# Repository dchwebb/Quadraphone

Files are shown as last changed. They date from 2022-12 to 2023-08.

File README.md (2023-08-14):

# Quadraphone
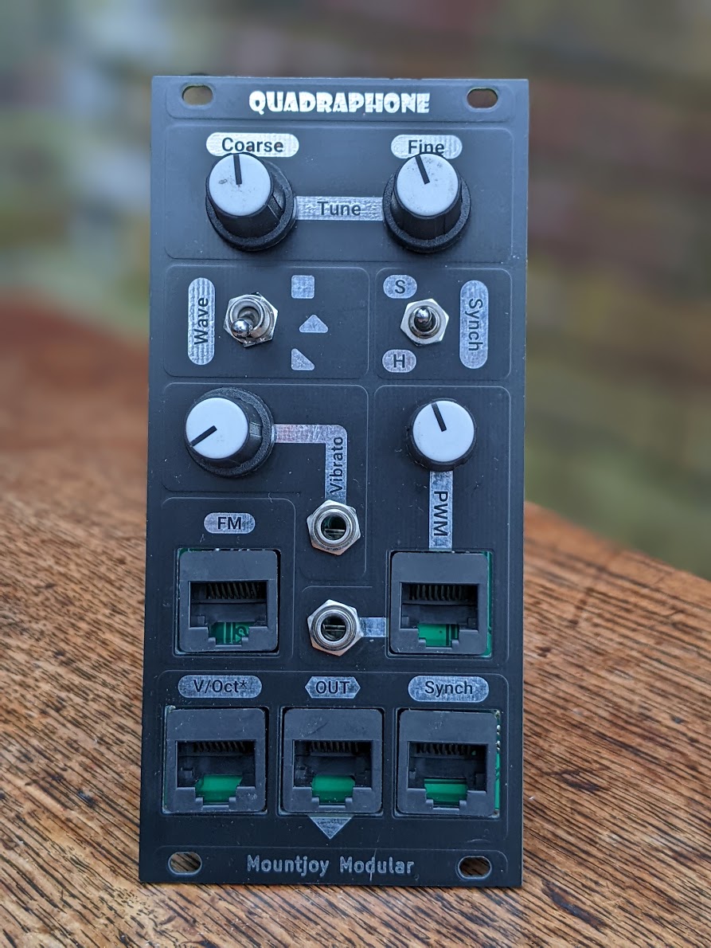
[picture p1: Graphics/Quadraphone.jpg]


Quadraphone
--------

Quadraphone is a four voice polyphonic analog Voltage Controlled Oscillator for use within a Eurorack Modular Synthesiser. Polyphonic signal interconnections are made via RJ-45 cables (ie Ethernet cables).

Quadraphone features a switchable output of square, triangle and saw waves. Pulse Width Modulation (PWM) is available for the square wave, polyphonically via an RJ-45 input or across all voices via a 3.5mm jack. A potentiometer sets the default pulse width across all voices.

Polyphonic synch is available and a switch allows selection of hard, soft or off settings. Exponentional FM is available on an Rj-45 connection and vibrato (linear FM) is available via a 3.5mm jack with potentiometer attenuation.

A volt per octave input is available on an RJ-45 connector. Pins 1-4 carry the control voltage input and pins 5-8 carry the output signal (also available on an RJ-45) for easy module interconnection. Coarse and Fine tune potentiometers affect all voices.

Technical
---------

Each Quadraphone voice is based around the [Sound Semiconductor SSI2131 Fatkeys VCO](https://www.soundsemiconductor.com/).

Each VCO outputs three voices (pulse, triangle and saw) which are switched via Nexperia 74LV4066PW analog switches. 74LV4066PW ICs are also used to switch incoming synch signals between the hard, soft and off selections.

Each voice has trimmers to control base frequency, exponential scaling and high frequency tracking.

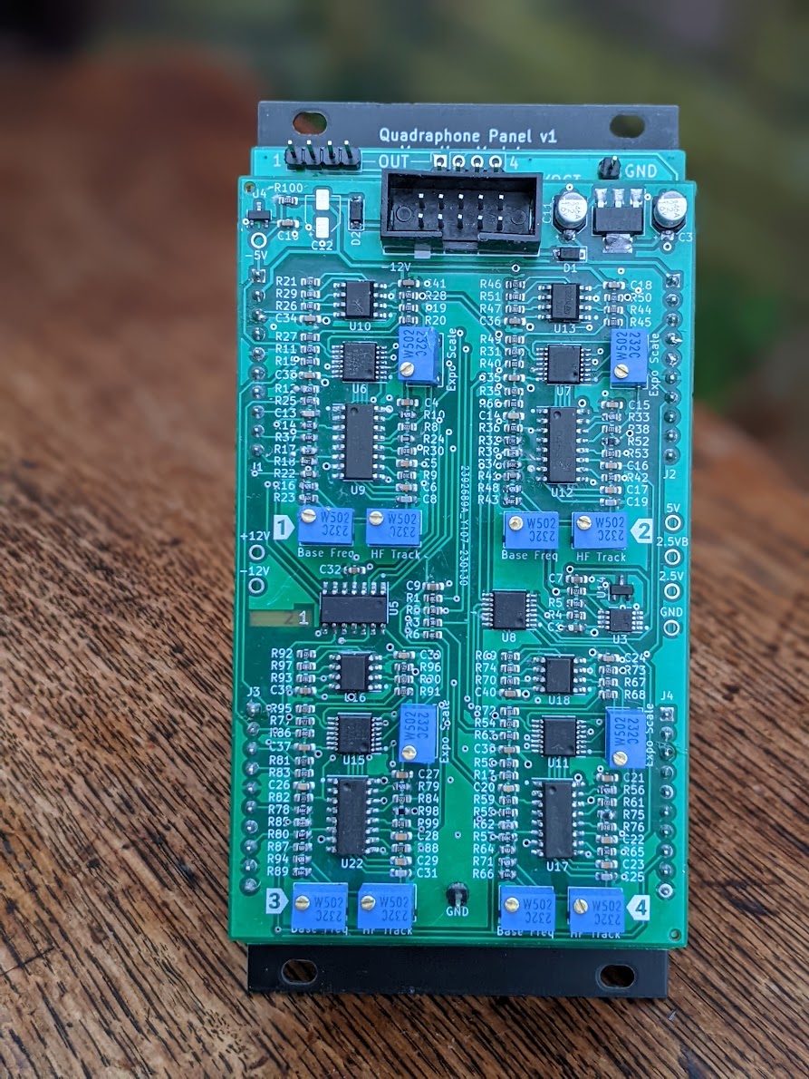
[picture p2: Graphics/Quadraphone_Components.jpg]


Construction is a sandwich of three PCBs with a component board, a controls board and a panel. PCBs designed in Kicad v6.

[Components schematic](https://raw.githubusercontent.com/dchwebb/Quadraphone/master/Quadraphone_Components.pdf)

[Controls schematic](https://raw.githubusercontent.com/dchwebb/Quadraphone/master/Quadraphone_Controls.pdf)

In addition the the Eurorack +/-12V rails (which have polarity protection and filtering) a 5v rail is supplied using an AMS1117-5.0 LDO. A 2.5v rail is generated with an LM4040DBZ-2.5 and buffered with an MCP6002 opamp and a -5v reference is generated with an LM4040DBZ-5.0.

+12V current draw: 44mA
-12V current draw: 34mA

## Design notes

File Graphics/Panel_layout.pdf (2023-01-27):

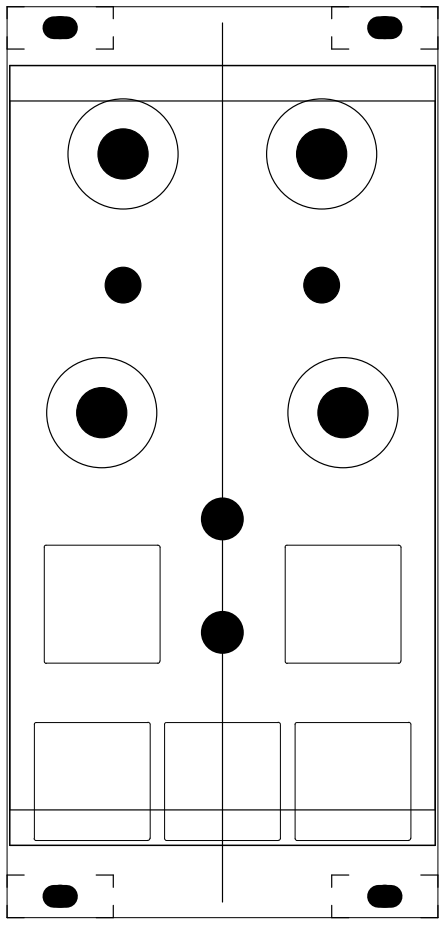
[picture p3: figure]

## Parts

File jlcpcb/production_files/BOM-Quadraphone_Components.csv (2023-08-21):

Comment | Designator | Footprint | LCSC
74LV4066PW | U11,U15,U6,U7,U8 | TSSOP-14_4.4x5mm_P0.65mm | C123051
2k7 | R7 | R_0603_1608Metric | C13167
100nF | C10,C18,C24,C30,C32,C33,C34,C35,C36,C37,C38,C39,C40,C41 | C_0603_1608Metric_Pad1.08x0.95mm_HandSolder | C14663
1uF | C1,C7,C9 | C_0603_1608Metric_Pad1.08x0.95mm_HandSolder | C15849
1nF | C13,C14,C20,C26 | C_0603_1608Metric_Pad1.08x0.95mm_HandSolder | C1588
MMBT3904 | Q1 | SOT-23 | C20526
13k | R1,R14,R2,R3,R36,R4,R59,R6,R82 | R_0603_1608Metric | C22797
1M | R30,R53,R76,R99 | R_0603_1608Metric | C22935
270 | R10,R16,R33,R48,R56,R71,R79,R94 | R_0603_1608Metric | C22966
30k | R19,R20,R26,R27,R44,R45,R47,R49,R67,R68,R70,R72,R90,R91,R93,R95 | R_0603_1608Metric | C22984
49.9k | R18,R22,R32,R34,R37,R41,R55,R57,R64,R78,R80,R87 | R_0603_1608Metric | C23184
510k | R24,R52,R75,R98 | R_0603_1608Metric | C23192
68k | R23,R43,R66,R89 | R_0603_1608Metric | C23231
100k | R13,R15,R25,R40,R60,R63,R83,R86 | R_0603_1608Metric | C25803
10k | R42,R65,R88,R9 | R_0603_1608Metric | C25804
120k | R12,R21,R28,R35,R46,R50,R58,R69,R73,R81,R92,R96 | R_0603_1608Metric | C25808
18k | R29,R51,R74,R97 | R_0603_1608Metric | C25810
47k | R102,R11,R31,R54,R77 | R_0603_1608Metric | C25819
680k | R17,R39,R62,R85 | R_0603_1608Metric | C25822
22k | R38,R61,R8,R84 | R_0603_1608Metric | C31850
20k | R101 | R_0603_1608Metric | C4184
2.2k | R100 | R_0603_1608Metric | C4190
10nF | C15,C16,C17,C21,C22,C23,C27,C28,C29,C4,C5,C6 | C_0603_1608Metric_Pad1.08x0.95mm_HandSolder | C57112
AMS1117-5.0 | U1 | SOT-223-3_TabPin2 | C6187
TL072 | U10,U13,U16,U18 | SOIC-8_3.9x4.9mm_P1.27mm | C6961
MCP6002 | U3 | SOIC-8_3.9x4.9mm_P1.27mm | C7377
1N5819 | D1,D2 | D_SOD-123 | C8598

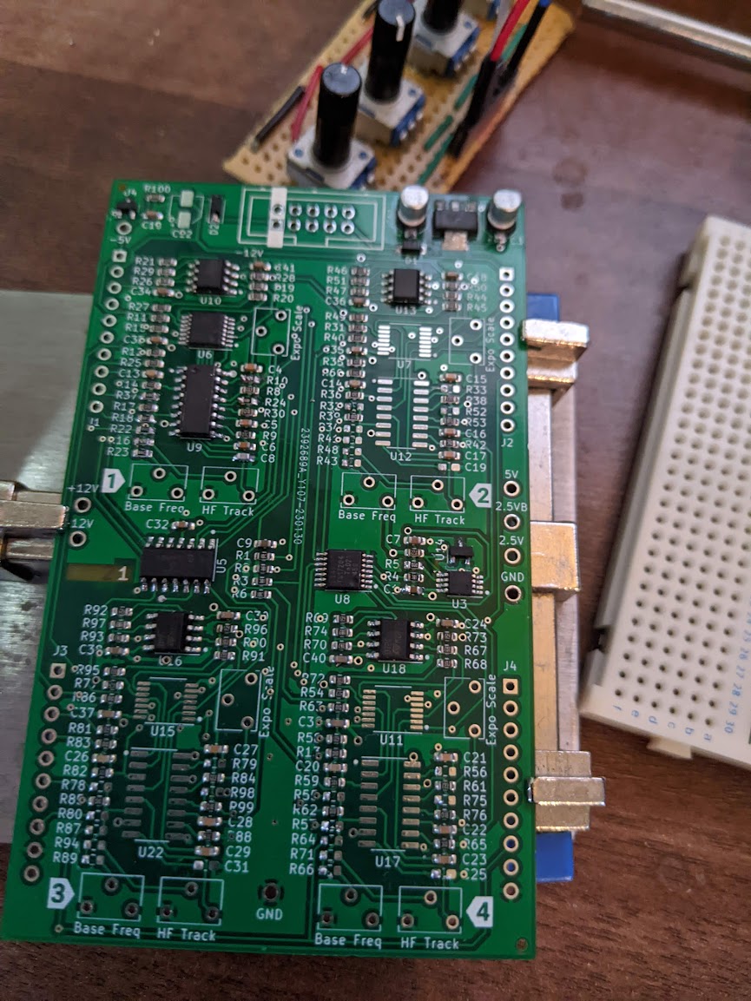
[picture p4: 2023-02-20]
Graphics/Component_Board_WIP.jpg

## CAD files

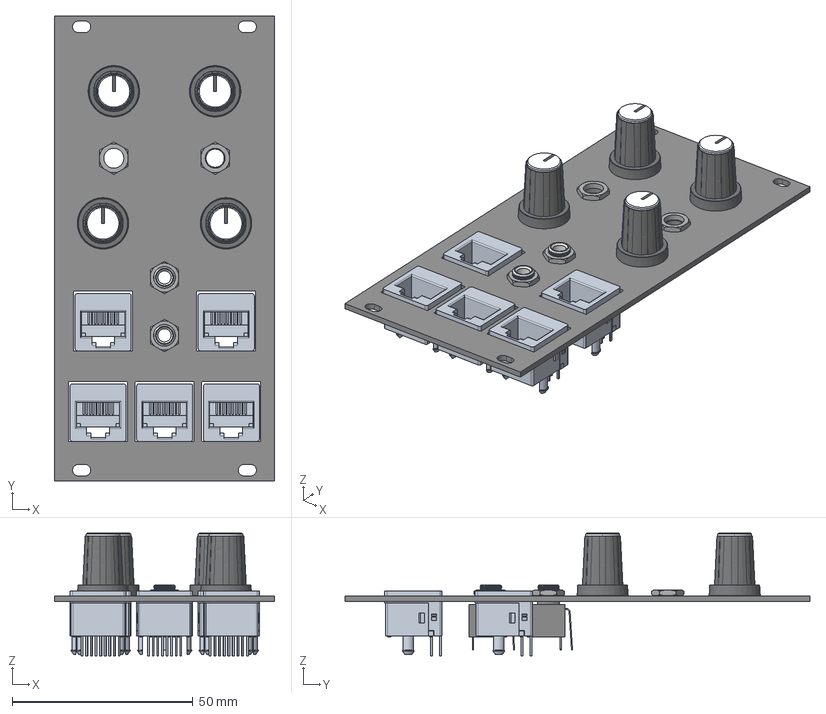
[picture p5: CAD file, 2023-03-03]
Graphics/Quadraphone_Panel.step
60.8 x 128.5 x 34.0 mm
Quadraphone_Panel PCB

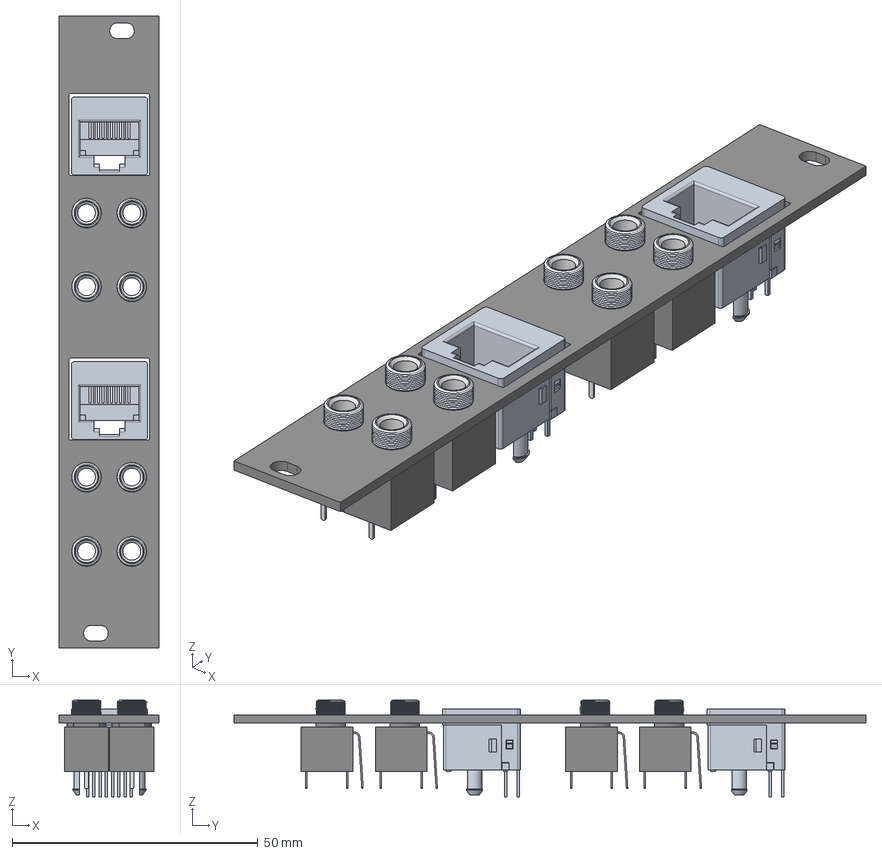
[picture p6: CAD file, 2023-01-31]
V2_Production/Quadraphone_Breakout_Panel.step
20.3 x 128.5 x 19.7 mm
Quadraphone_Breakout_Panel PCB

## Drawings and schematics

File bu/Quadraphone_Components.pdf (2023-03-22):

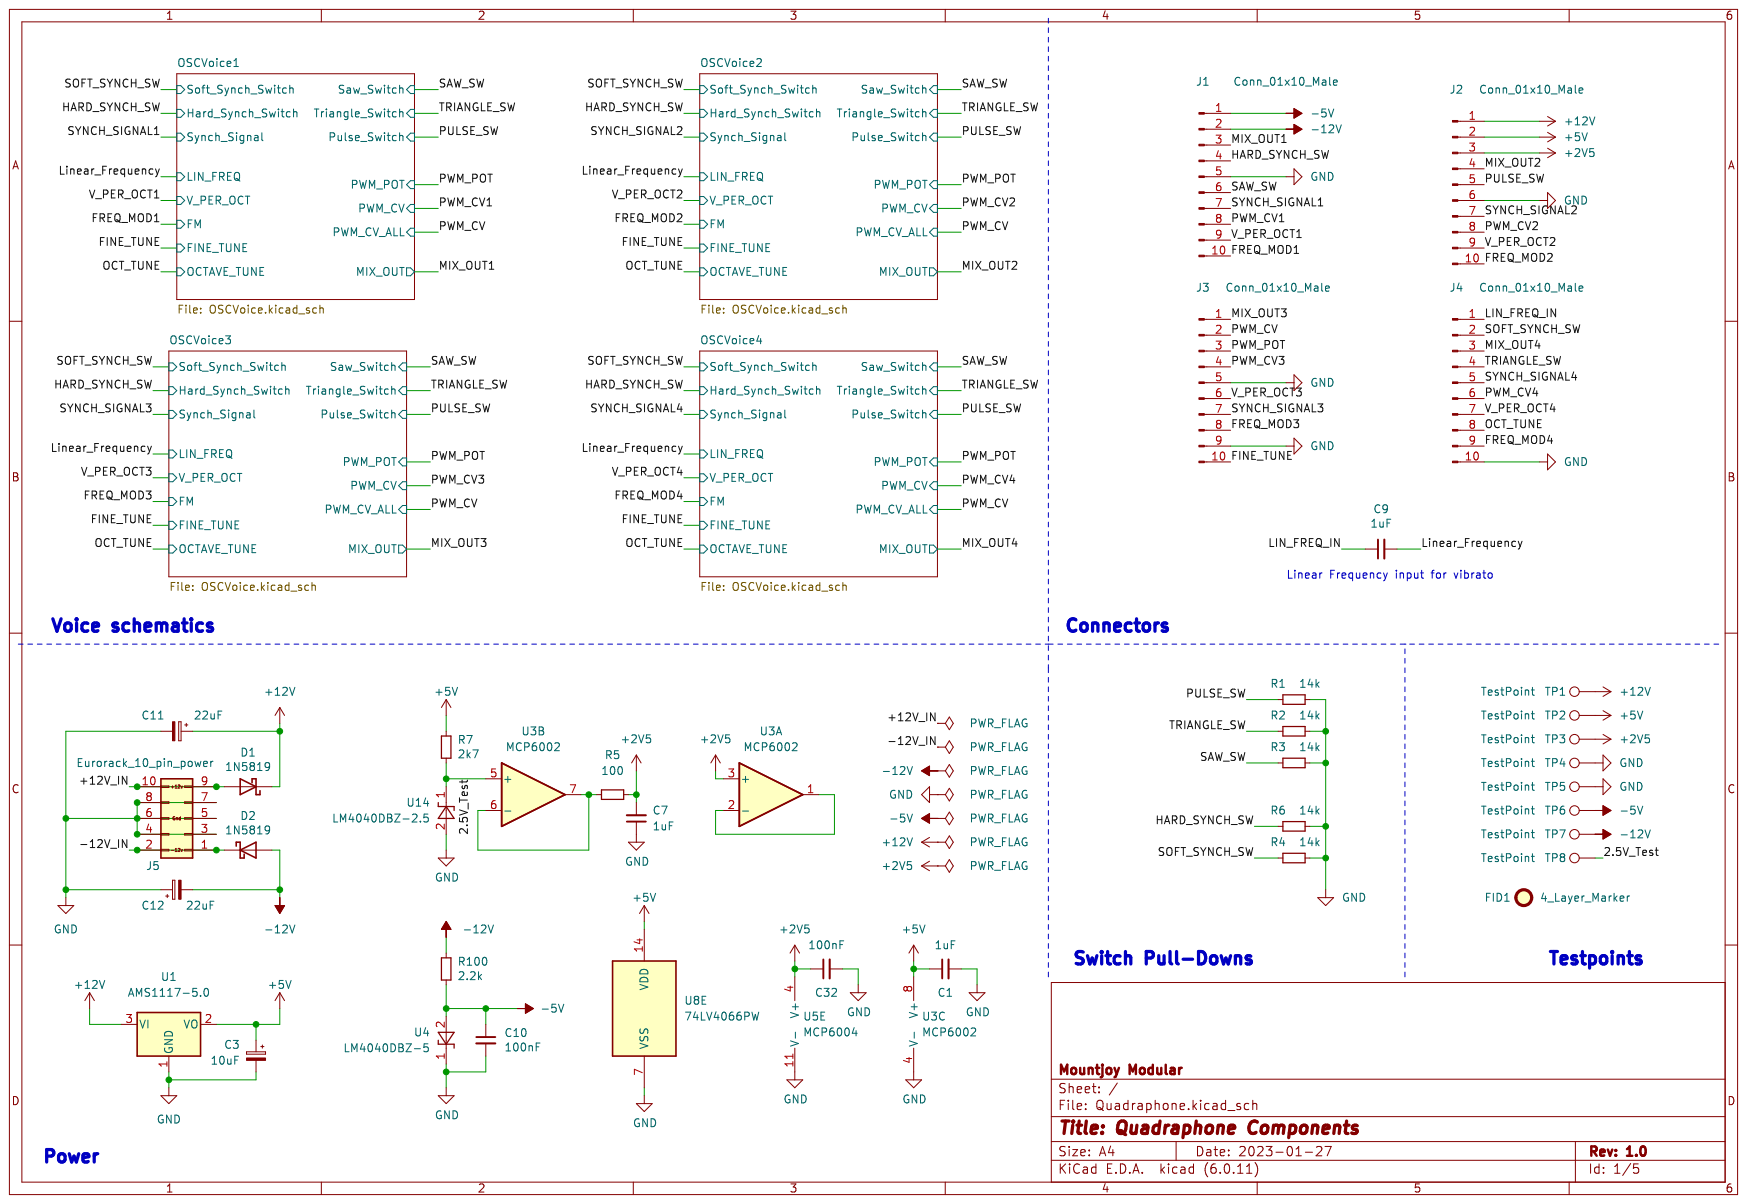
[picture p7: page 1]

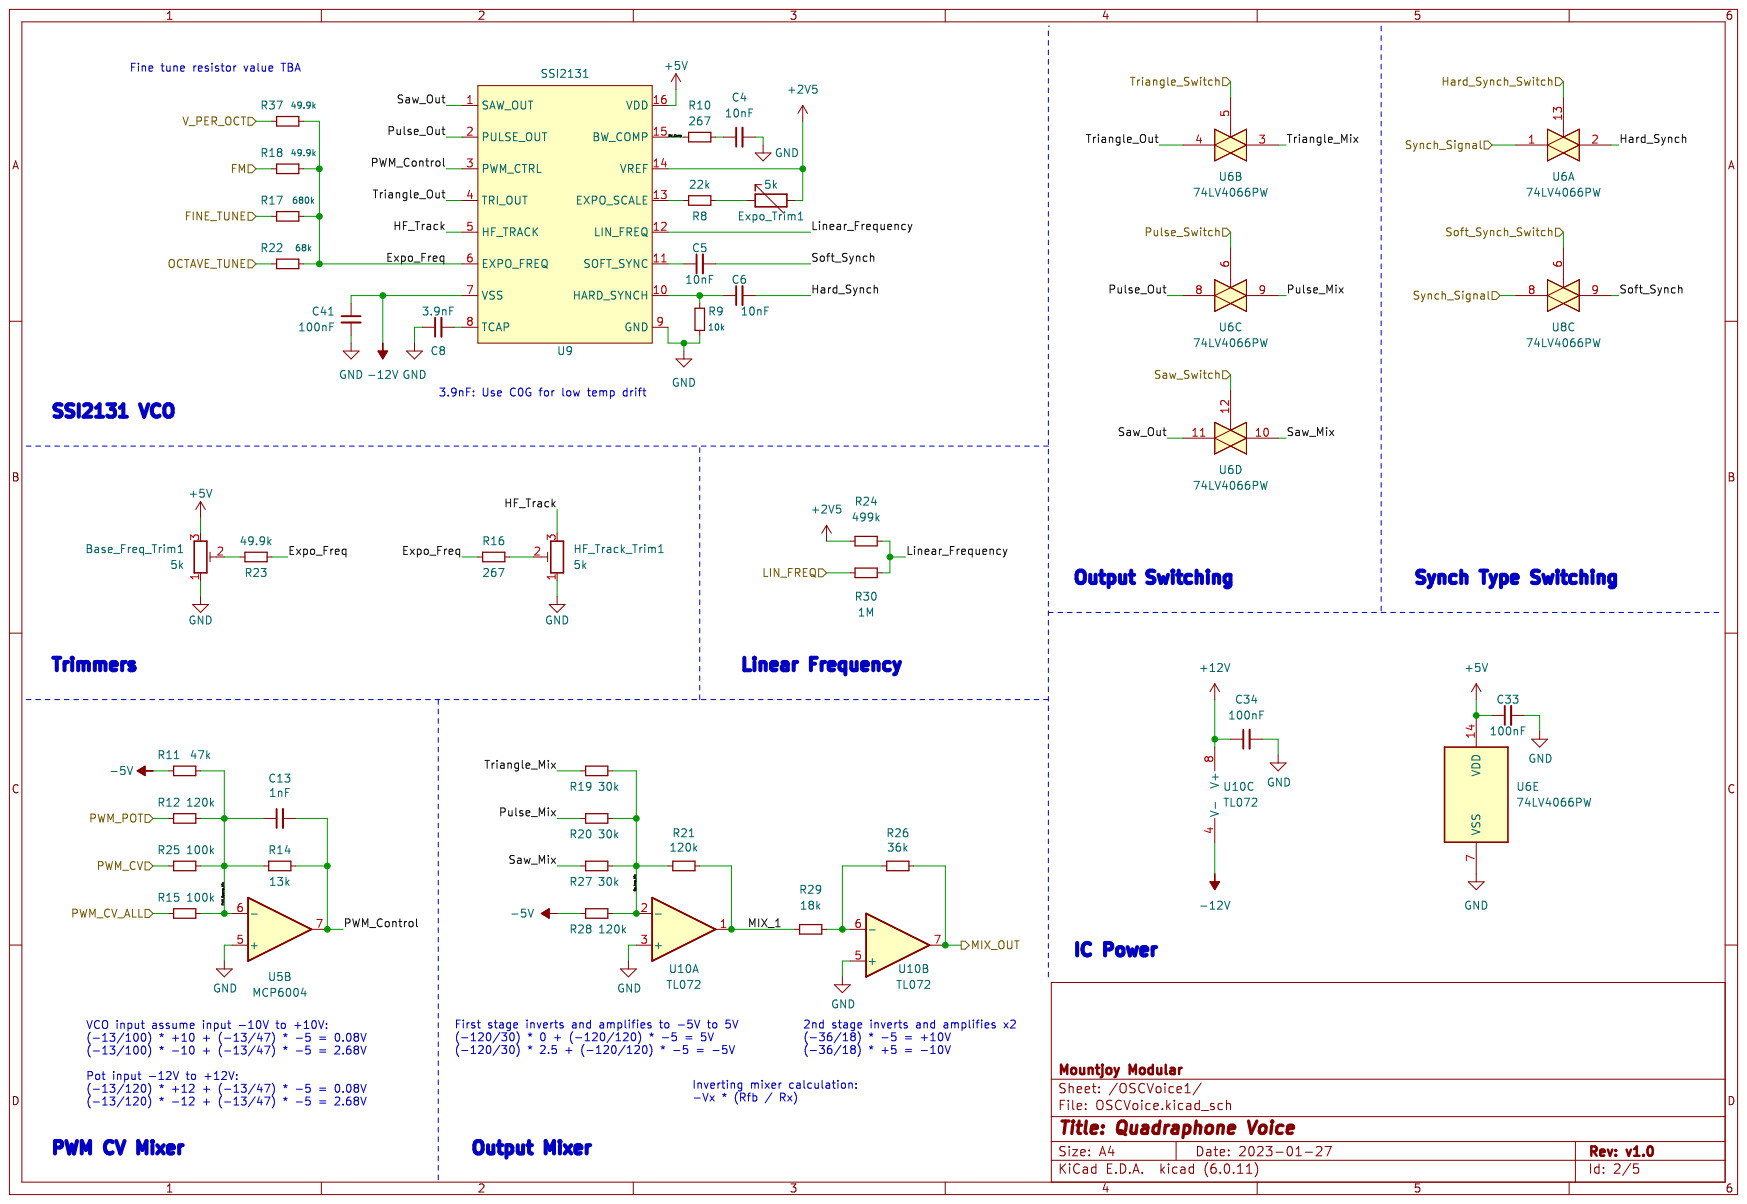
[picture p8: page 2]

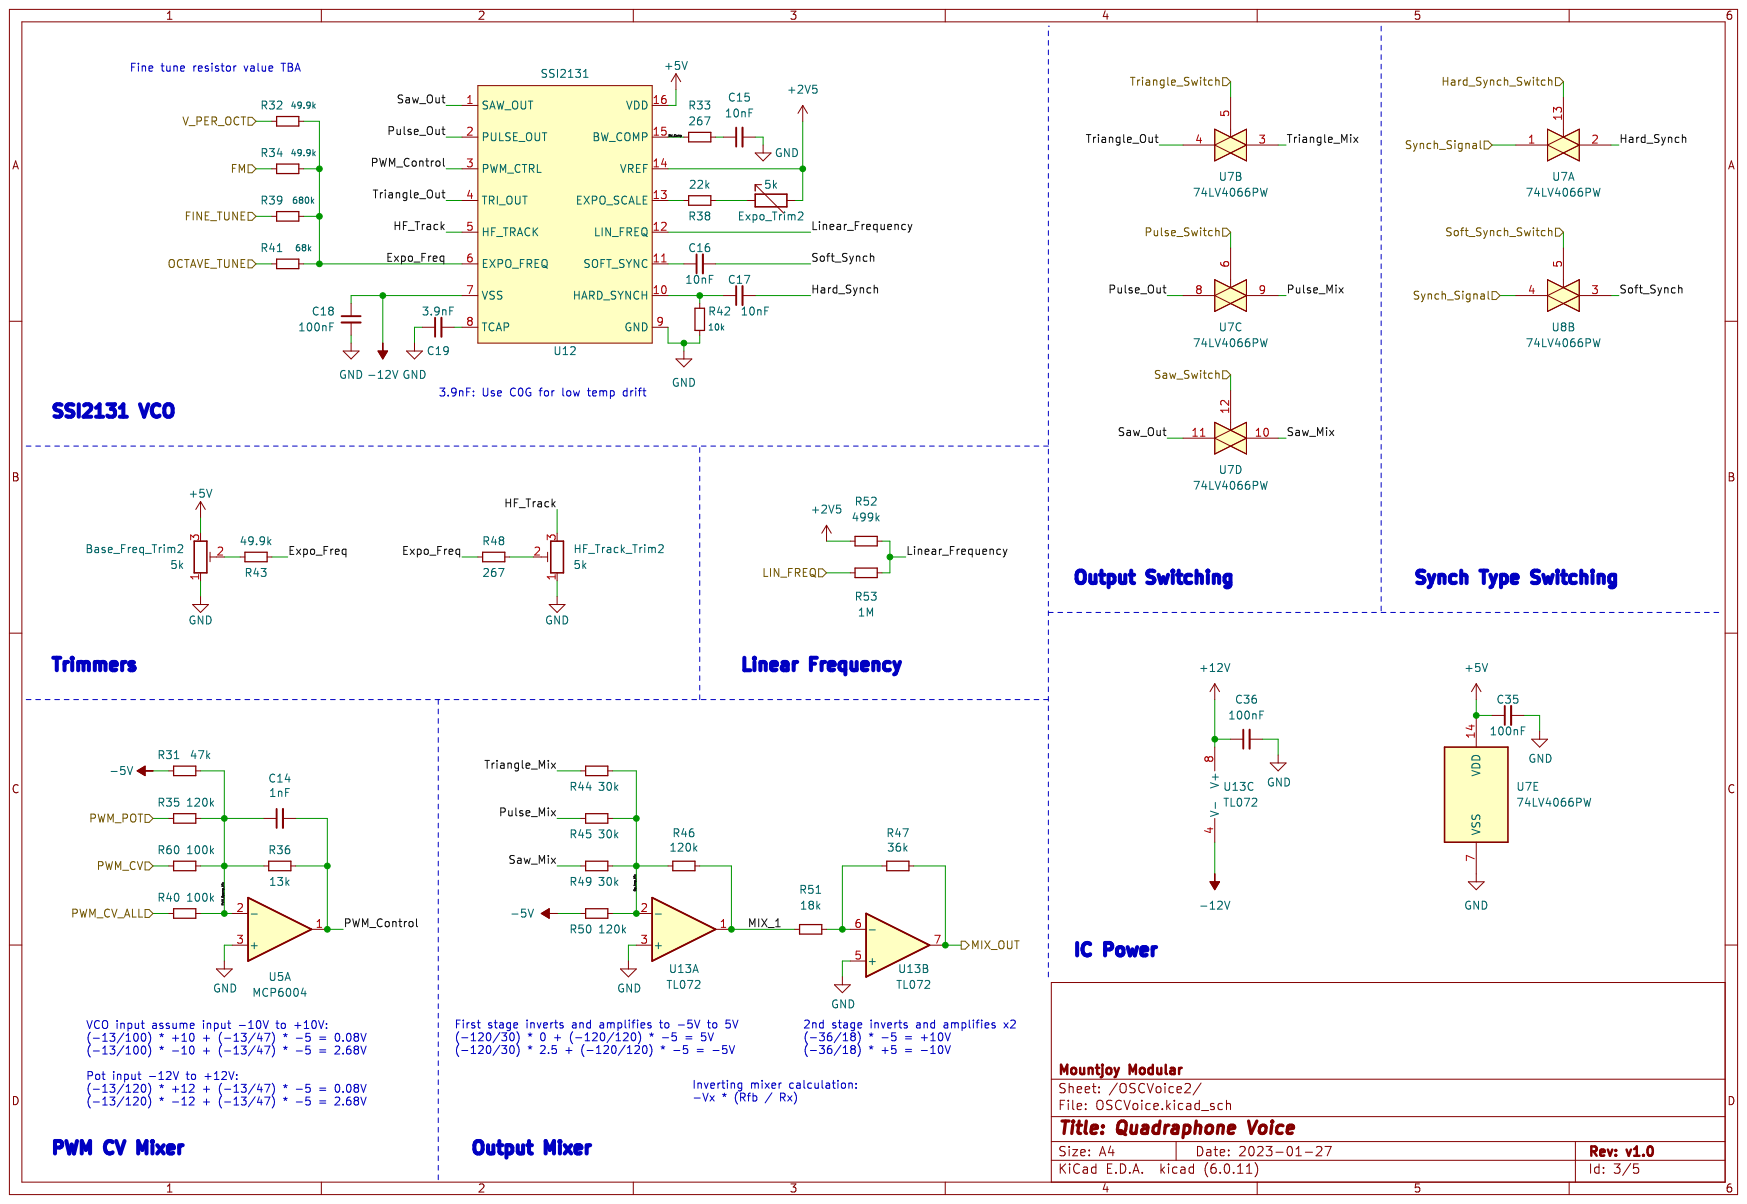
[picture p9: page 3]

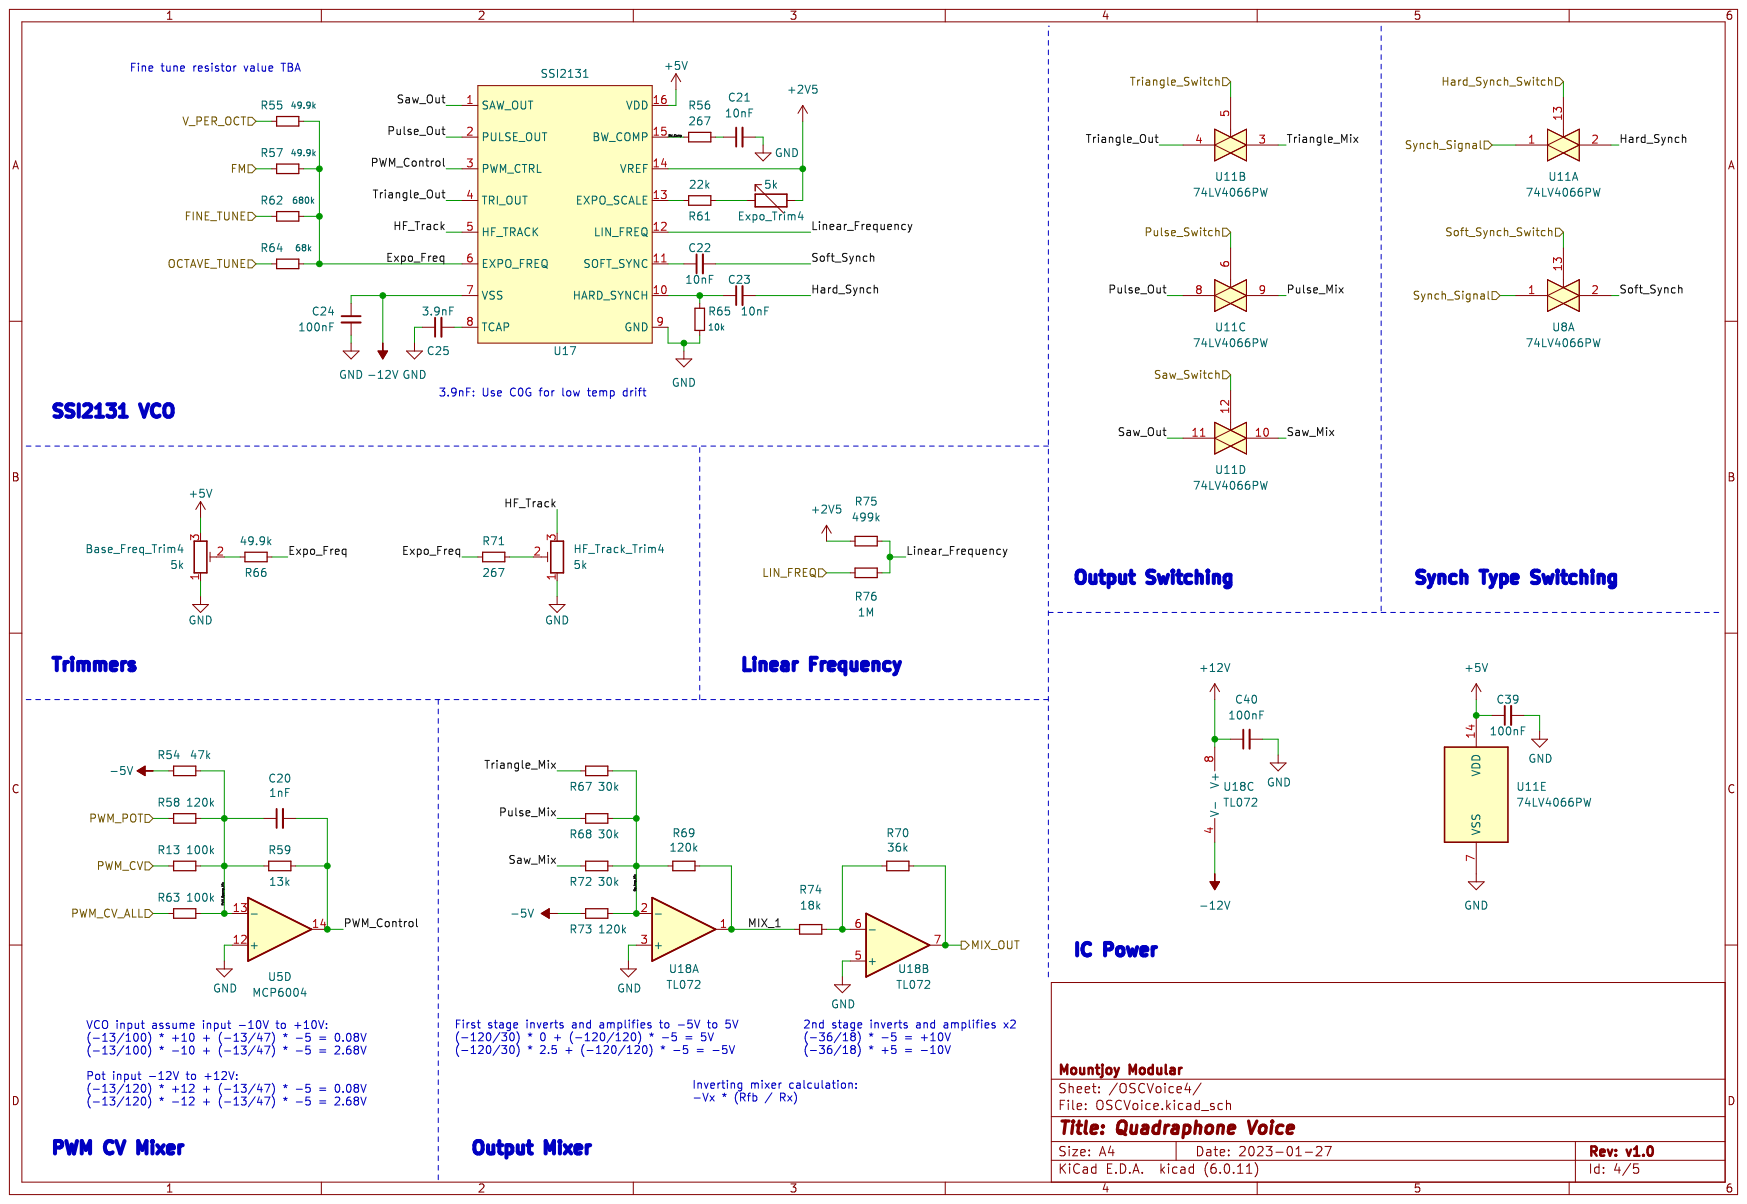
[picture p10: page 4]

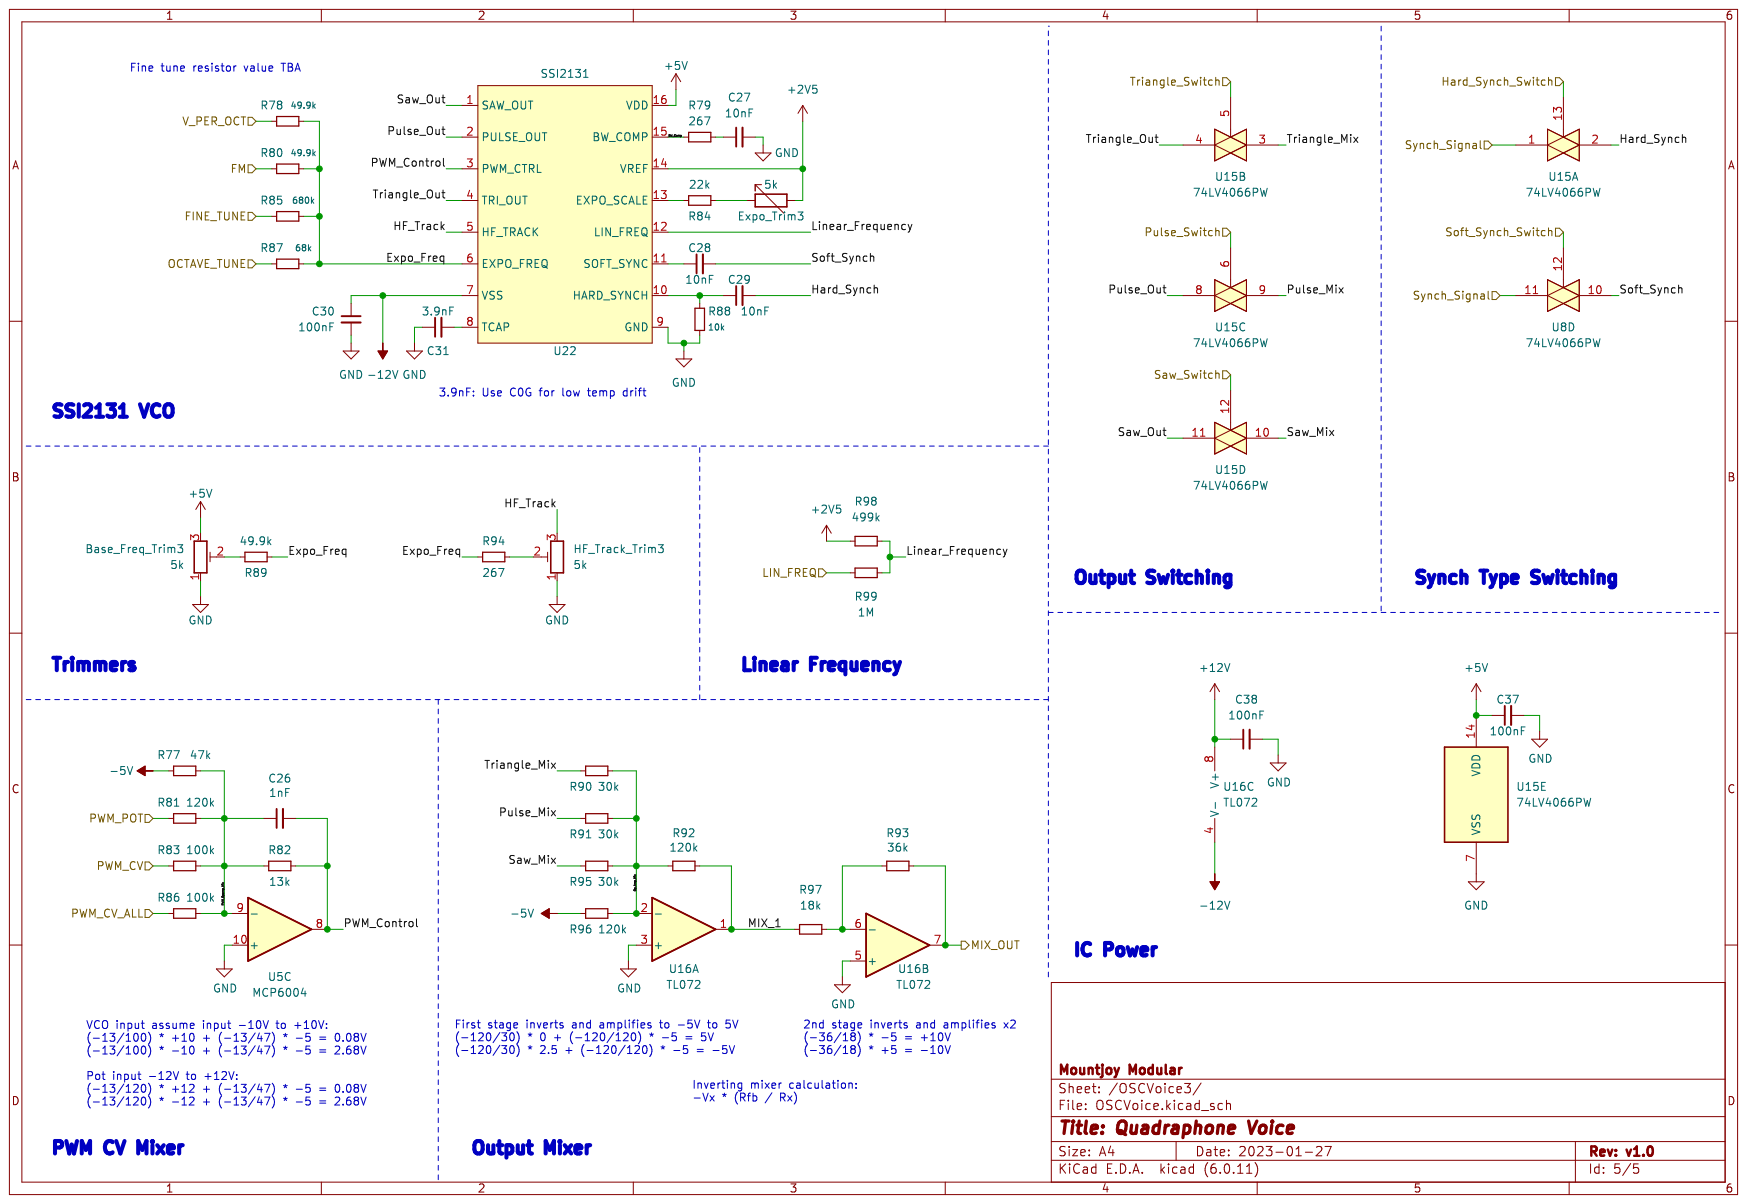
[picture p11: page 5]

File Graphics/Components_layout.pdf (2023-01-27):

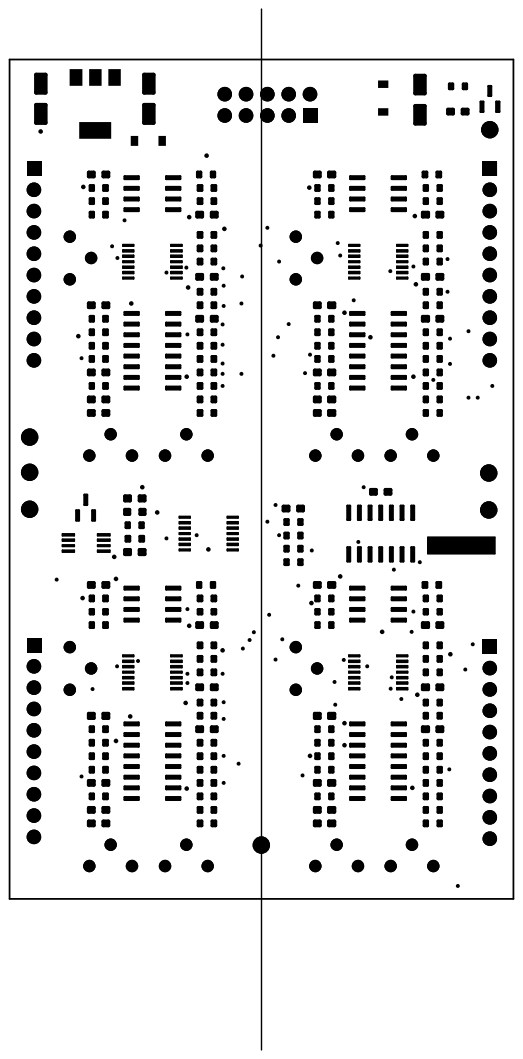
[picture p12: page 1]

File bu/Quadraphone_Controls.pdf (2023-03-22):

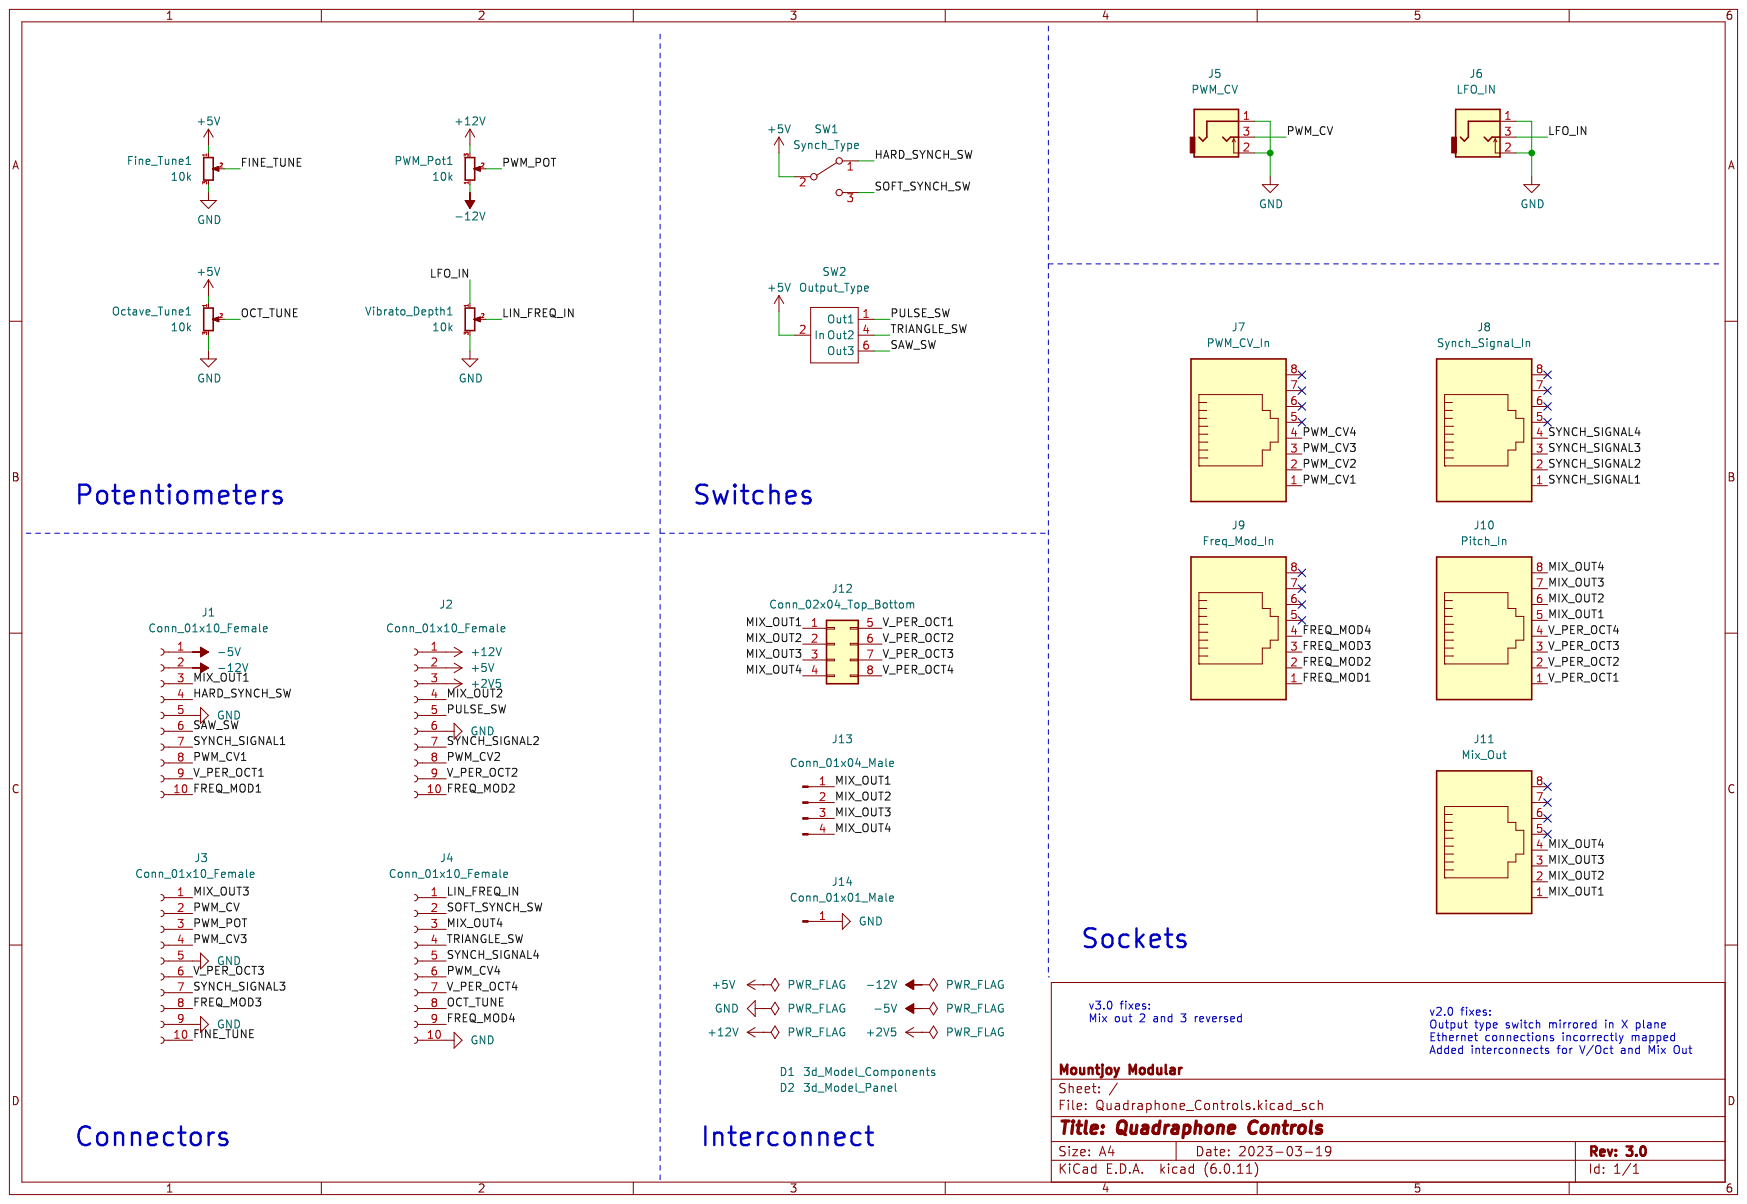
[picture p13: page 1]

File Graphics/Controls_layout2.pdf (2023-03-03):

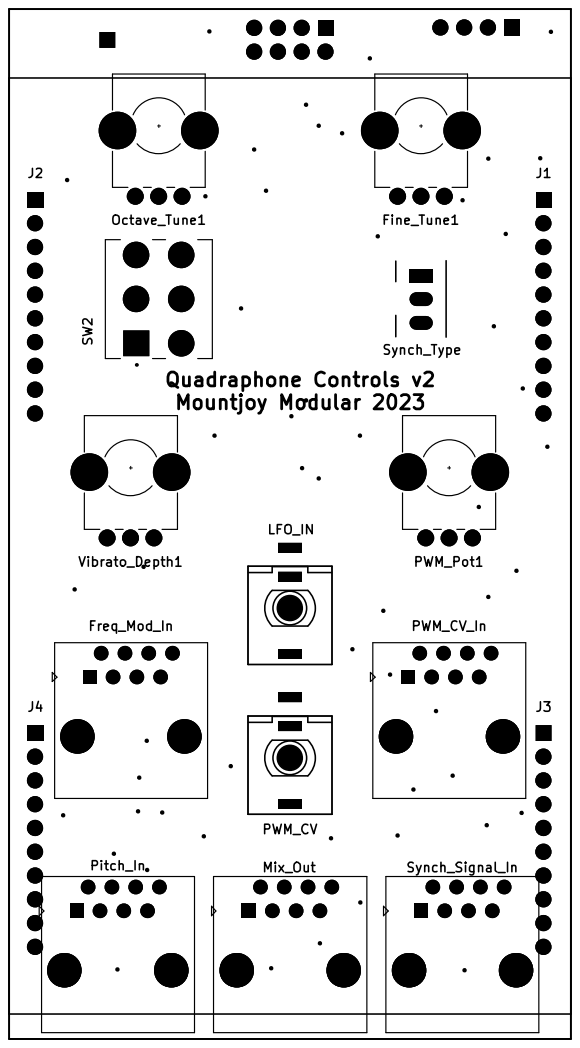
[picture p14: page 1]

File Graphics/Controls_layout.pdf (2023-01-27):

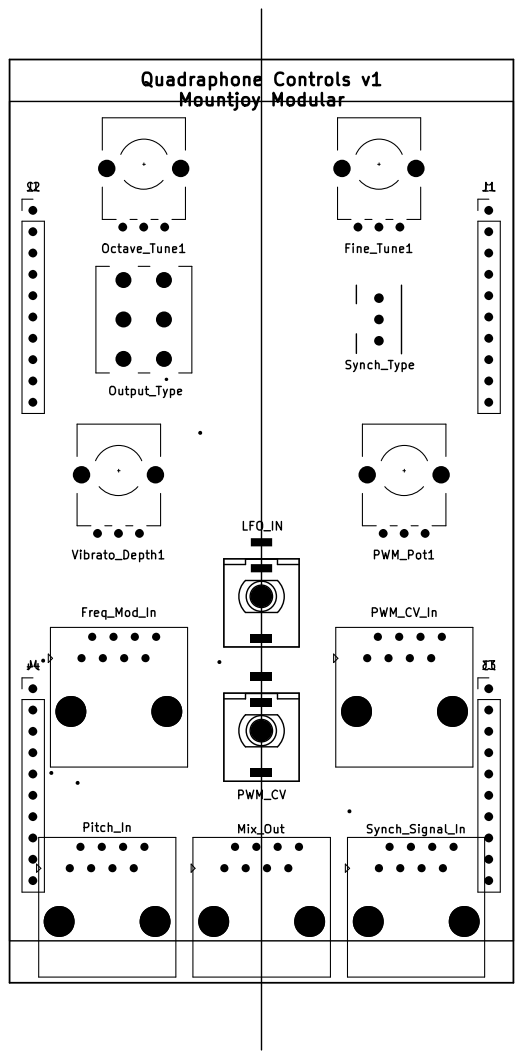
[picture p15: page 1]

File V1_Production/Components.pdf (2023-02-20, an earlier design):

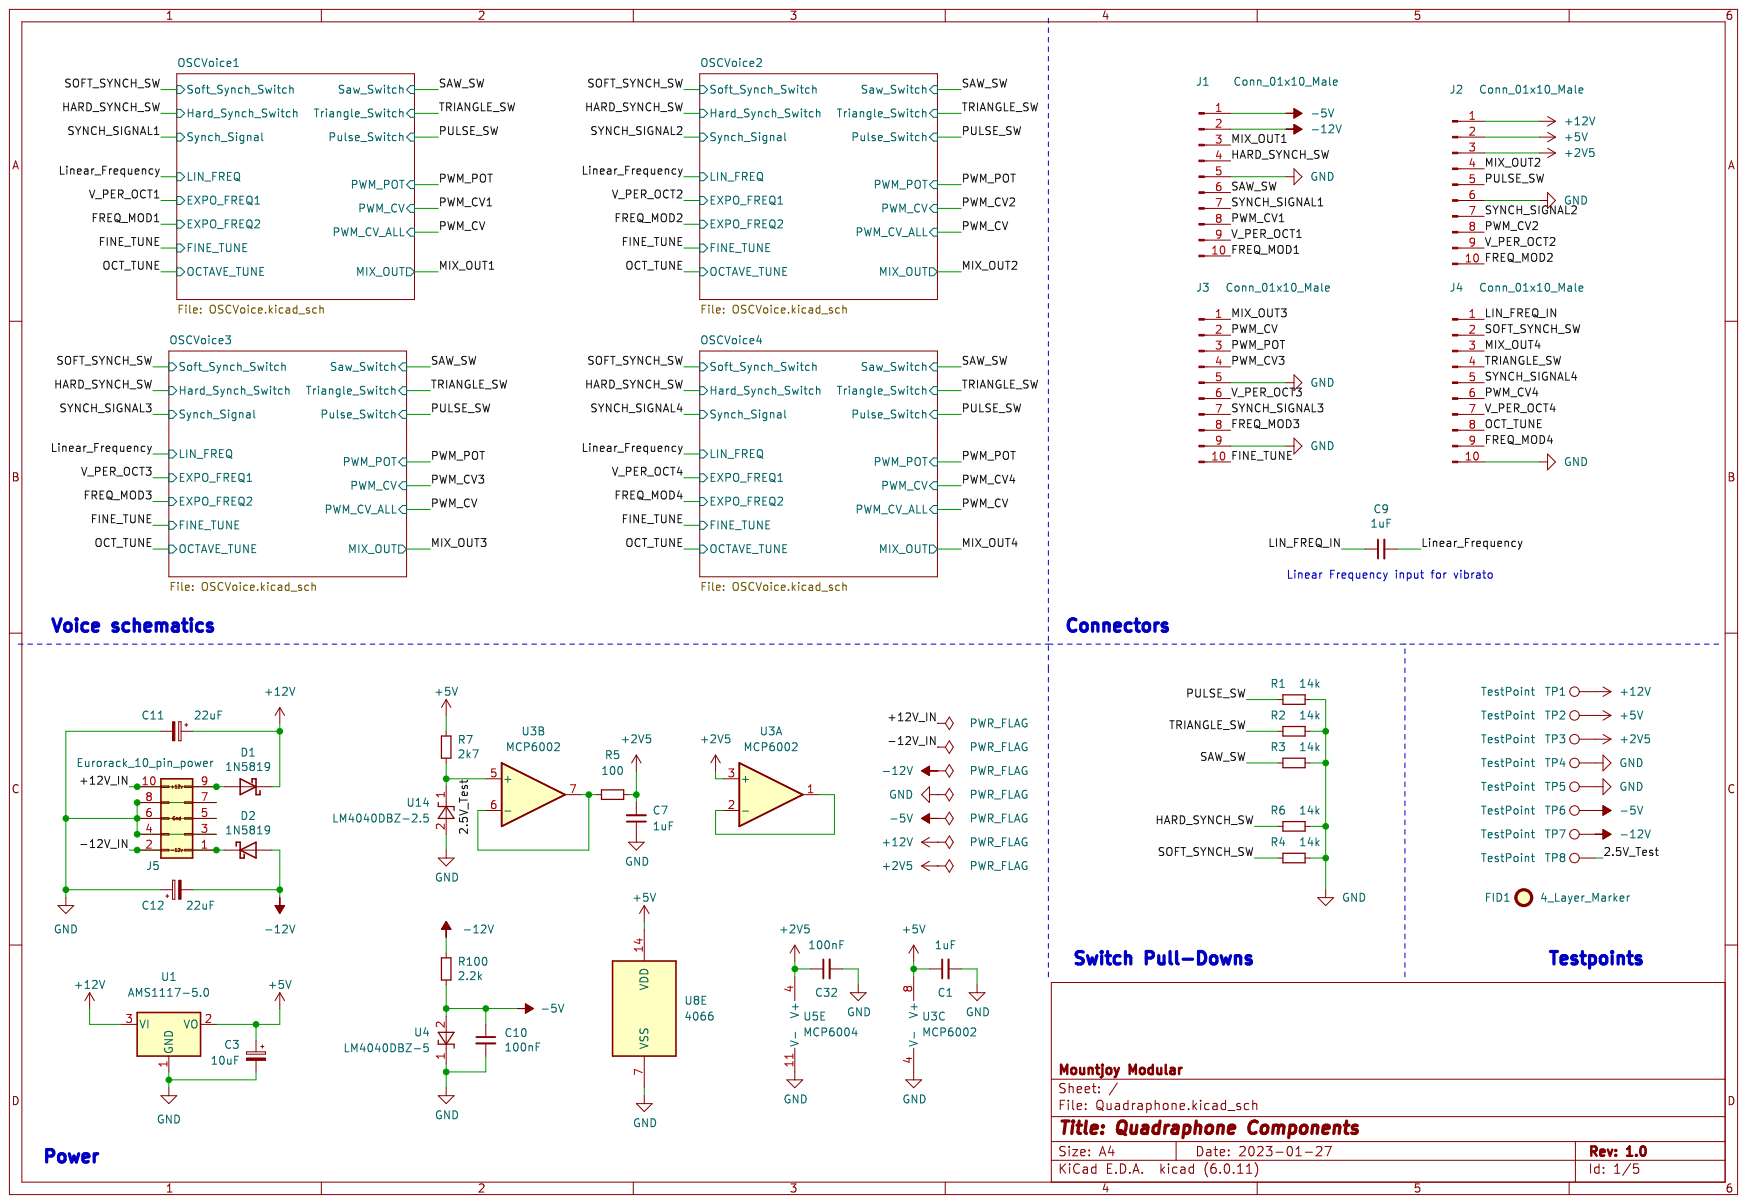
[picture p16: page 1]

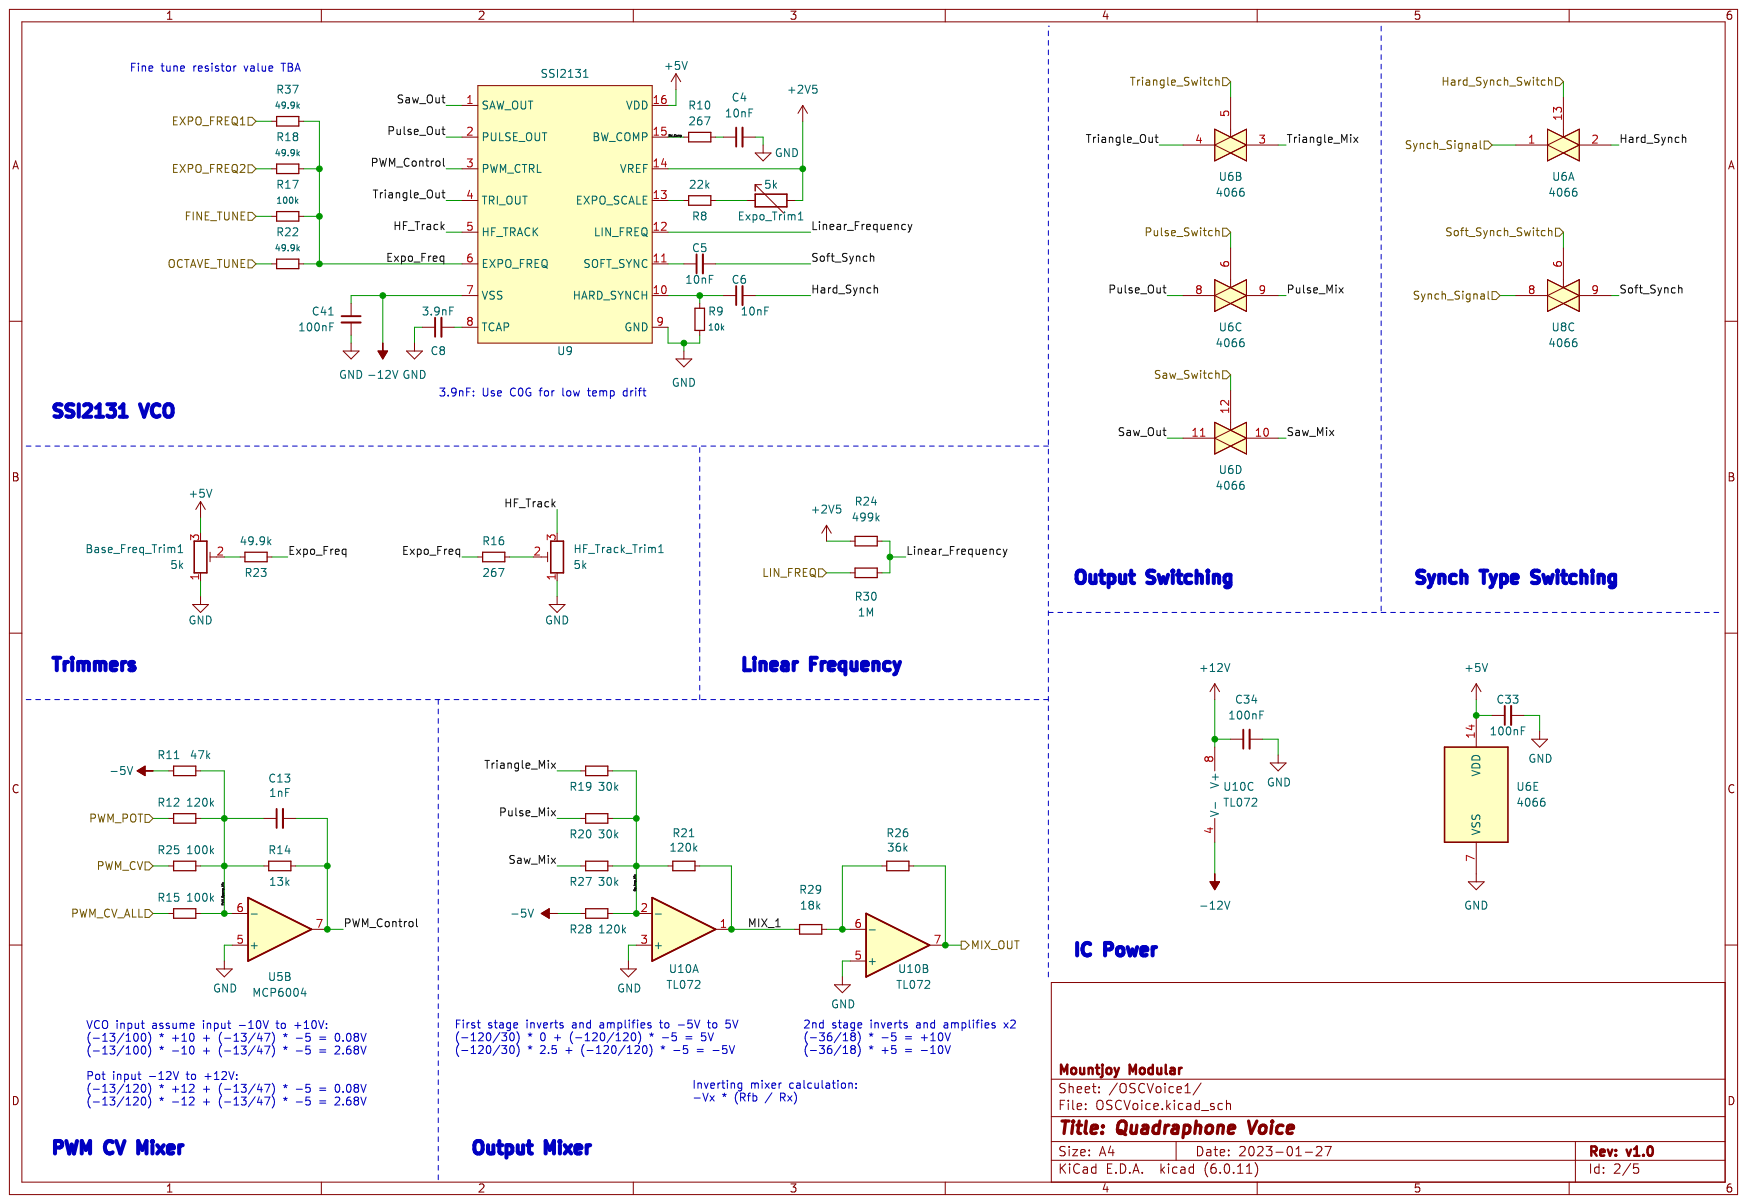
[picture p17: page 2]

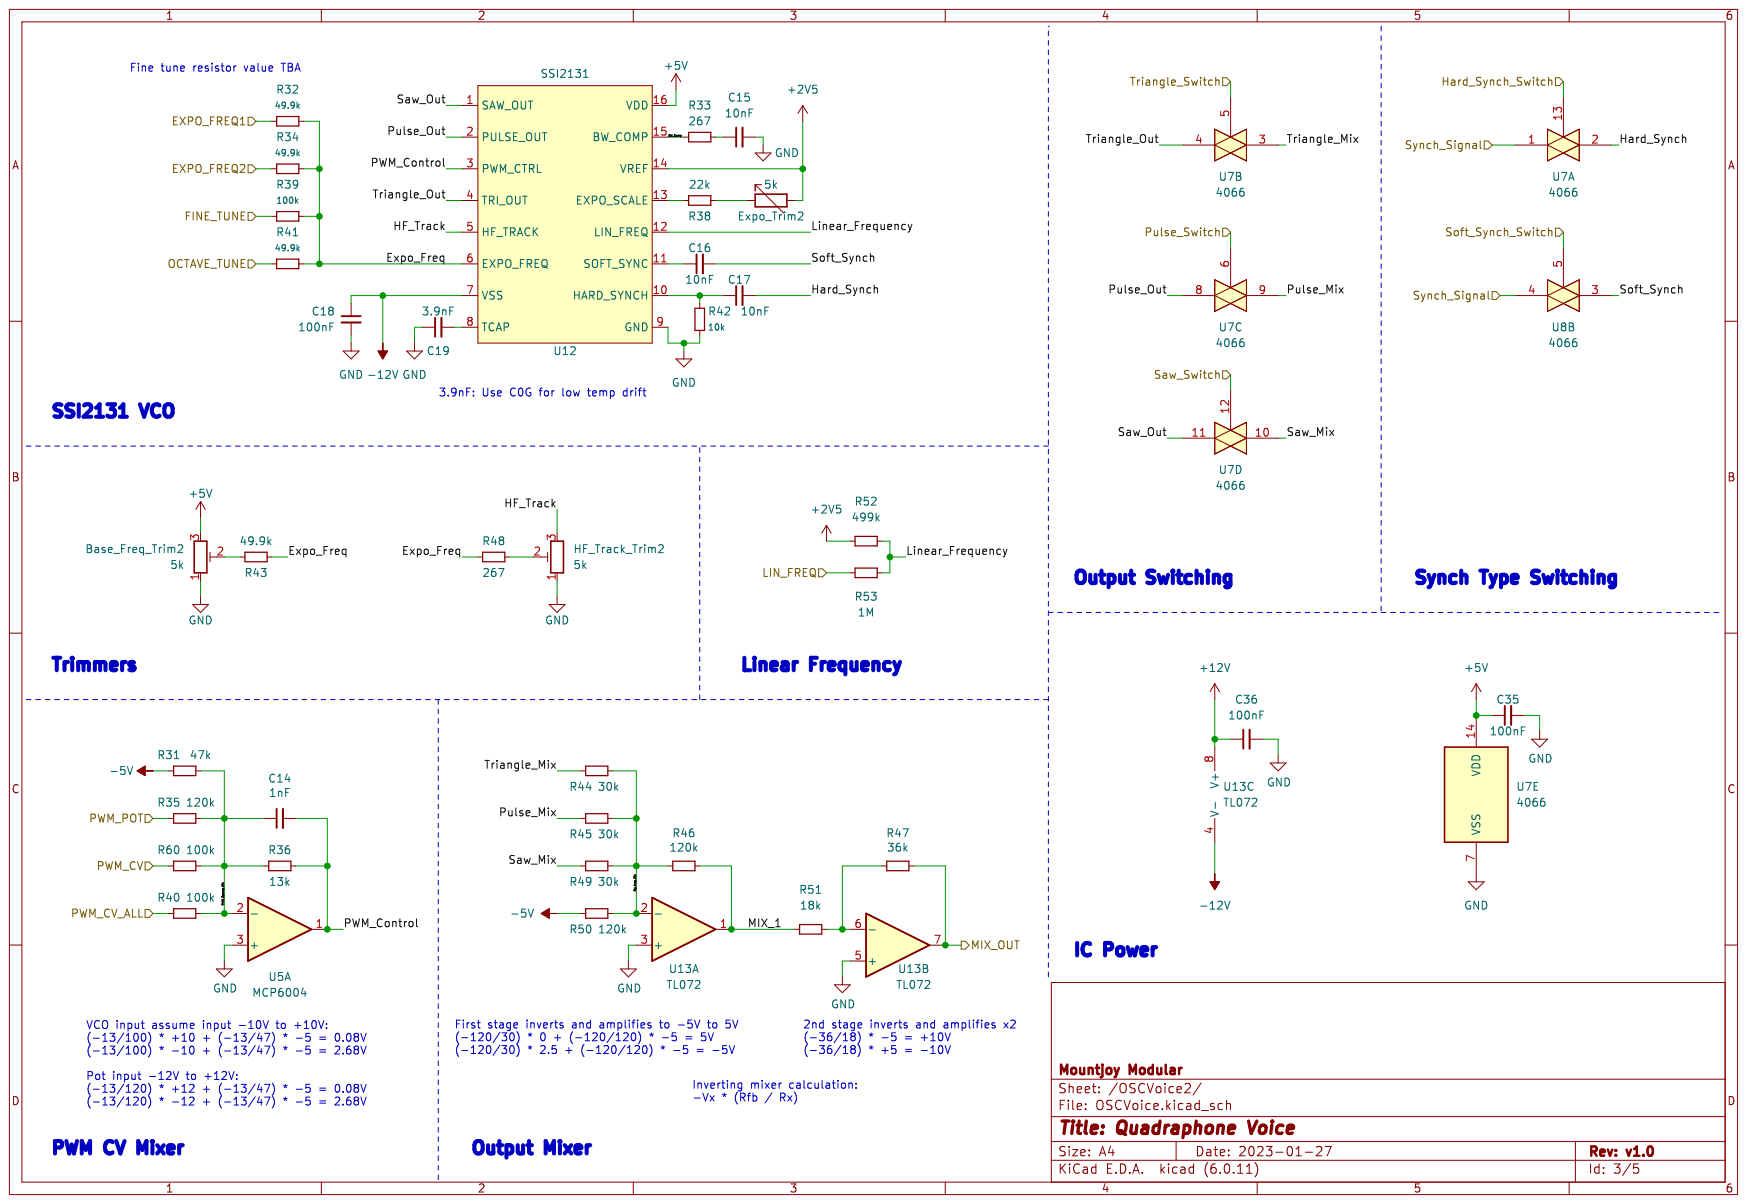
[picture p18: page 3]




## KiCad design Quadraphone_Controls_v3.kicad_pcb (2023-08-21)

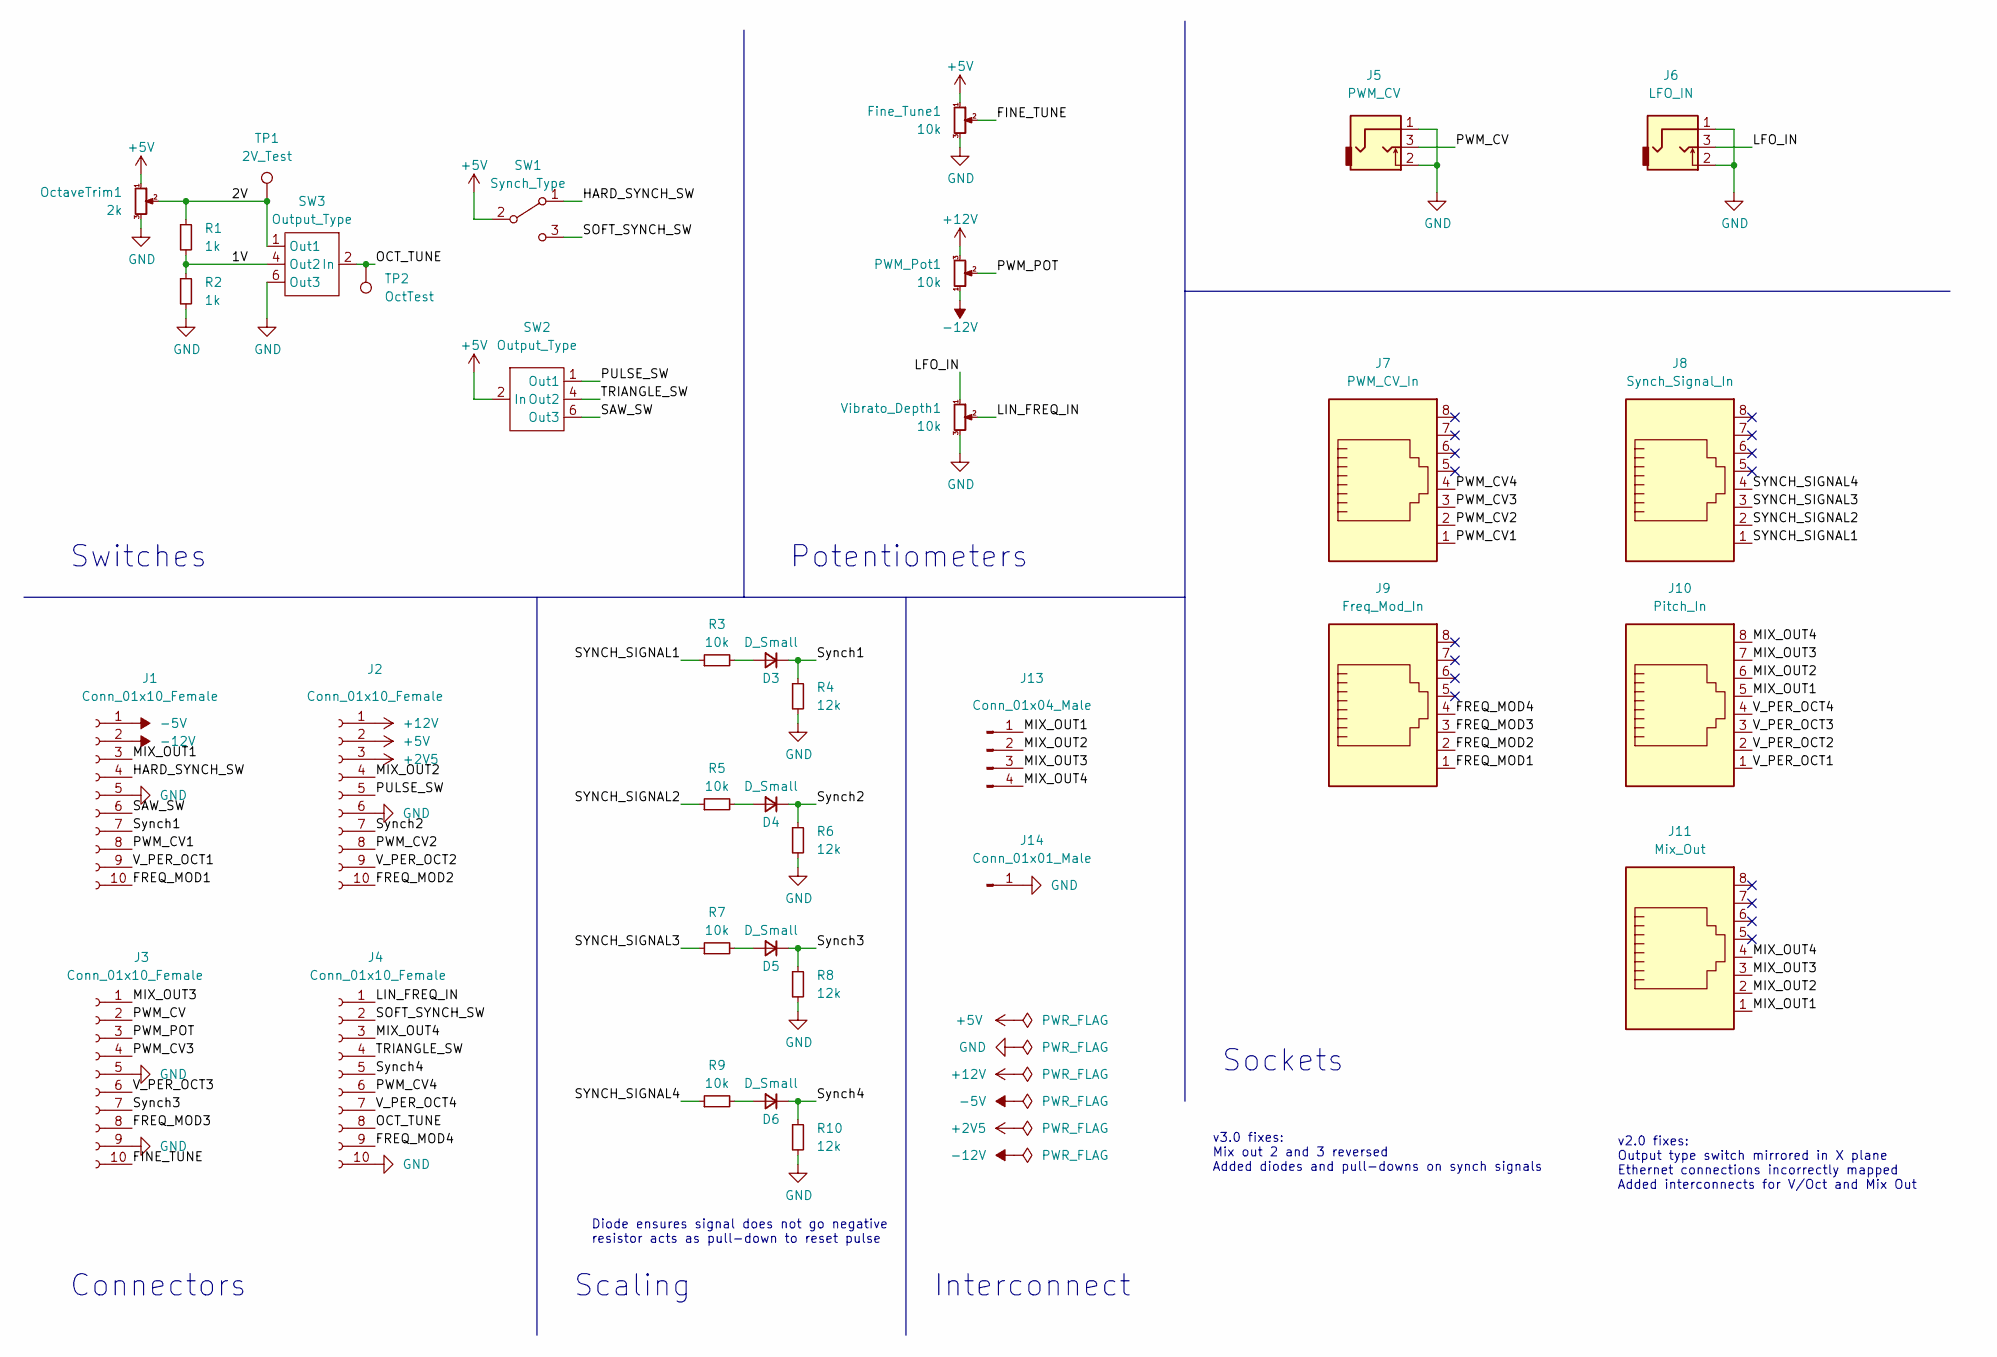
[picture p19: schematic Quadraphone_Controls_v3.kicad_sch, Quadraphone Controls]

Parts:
D3, D4, D5, D6: D_Small; D_0603_1608Metric_Pad1.05x0.95mm_HandSolder
Fine_Tune1: 10k; Alpha_9mm_Potentiometer_Aligned
J1, J2, J3, J4: Conn_01x10_Female; PinSocket_1x10_P2.54mm_Vertical
J5: PWM_CV; THONKICONN_hole
J6: LFO_IN; THONKICONN_hole
J7: PWM_CV_In; RJ45_Molex_42878-8506
J8: Synch_Signal_In; RJ45_Molex_42878-8506
J9: Freq_Mod_In; RJ45_Molex_42878-8506
J10: Pitch_In; RJ45_Molex_42878-8506
J11: Mix_Out; RJ45_Molex_42878-8506
J13: Conn_01x04_Male; PinHeader_1x04_P2.54mm_Vertical
J14: Conn_01x01_Male; PinHeader_1x01_P2.54mm_Vertical
OctaveTrim1: 2k; Potentiometer_Bourns_3266W_Vertical
PWM_Pot1: 10k; Alpha_9mm_Potentiometer_Aligned
R1, R2: 1k; R_0805_2012Metric
R3, R5, R7, R9: 10k; R_0805_2012Metric
R4, R6, R8, R10: 12k; R_0805_2012Metric
SW1: Synch_Type; SPDTSubMiniature
SW2, SW3: Output_Type; 100DP6T1B1M2QE_ON_ON_ON
TP1: 2V_Test; 1mm_Test_Point
TP2: OctTest; 1mm_Test_Point
Vibrato_Depth1: 10k; Alpha_9mm_Potentiometer_Aligned

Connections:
+2V5: J2.3
+5V: Fine_Tune1.1, J2.2, OctaveTrim1.1, SW1.2 (B), SW2.2 (In)
+12V: J2.1, PWM_Pot1.3
-5V: J1.1
-12V: J1.2, PWM_Pot1.1
/1V: R1.2, R2.1, SW3.4 (Out2)
/2V: OctaveTrim1.2, R1.1, SW3.1 (Out1), TP1.1
/FINE_TUNE: Fine_Tune1.2, J3.10
/FREQ_MOD1: J1.10, J9.1
/FREQ_MOD2: J2.10, J9.2
/FREQ_MOD3: J3.8, J9.3
/FREQ_MOD4: J4.9, J9.4
/HARD_SYNCH_SW: J1.4, SW1.1 (A)
/LFO_IN: J6.3, Vibrato_Depth1.1
/LIN_FREQ_IN: J4.1, Vibrato_Depth1.2
/MIX_OUT1: J1.3, J10.5, J11.1, J13.1
/MIX_OUT2: J2.4, J10.6, J11.2, J13.2
/MIX_OUT3: J3.1, J10.7, J11.3, J13.3
/MIX_OUT4: J4.3, J10.8, J11.4, J13.4
/OCT_TUNE: J4.8, SW3.2 (In), TP2.1
/PULSE_SW: J2.5, SW2.1 (Out1)
/PWM_CV: J3.2, J5.3
/PWM_CV1: J1.8, J7.1
/PWM_CV2: J2.8, J7.2
/PWM_CV3: J3.4, J7.3
/PWM_CV4: J4.6, J7.4
/PWM_POT: J3.3, PWM_Pot1.2
/SAW_SW: J1.6, SW2.6 (Out3)
/SOFT_SYNCH_SW: J4.2, SW1.3 (C)
/SYNCH_SIGNAL1: J8.1, R3.1
/SYNCH_SIGNAL2: J8.2, R5.1
/SYNCH_SIGNAL3: J8.3, R7.1
/SYNCH_SIGNAL4: J8.4, R9.1
/Synch1: D3.1 (K), J1.7, R4.1
/Synch2: D4.1 (K), J2.7, R6.1
/Synch3: D5.1 (K), J3.7, R8.1
/Synch4: D6.1 (K), J4.5, R10.1
/TRIANGLE_SW: J4.4, SW2.4 (Out2)
/V_PER_OCT1: J1.9, J10.1
/V_PER_OCT2: J2.9, J10.2
/V_PER_OCT3: J3.6, J10.3
/V_PER_OCT4: J4.7, J10.4
GND: Fine_Tune1.3, J1.5, J2.6, J3.5, J3.9, J4.10, J5.1, J5.2, J6.1, J6.2, J14.1, OctaveTrim1.3, R2.2, R4.2, R6.2, R8.2, R10.2, SW3.6 (Out3), Vibrato_Depth1.3
unnamed: D3.2 (A), R3.2
unnamed: D4.2 (A), R5.2
unnamed: D5.2 (A), R7.2
unnamed: D6.2 (A), R9.2
unnamed: SW2.3 (Pin3), SW2.5 (Pin5)
unnamed: SW3.3 (Pin3), SW3.5 (Pin5)

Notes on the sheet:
Connectors
Diode ensures signal does not go negative resistor acts as pull-down to reset pulse
Scaling
Potentiometers
v2.0 fixes: Output type switch mirrored in X plane Ethernet connections incorrectly mapped Added interconnects for V/Oct and Mix Out
v3.0 fixes: Mix out 2 and 3 reversed Added diodes and pull-downs on synch signals
Sockets
Switches
Interconnect

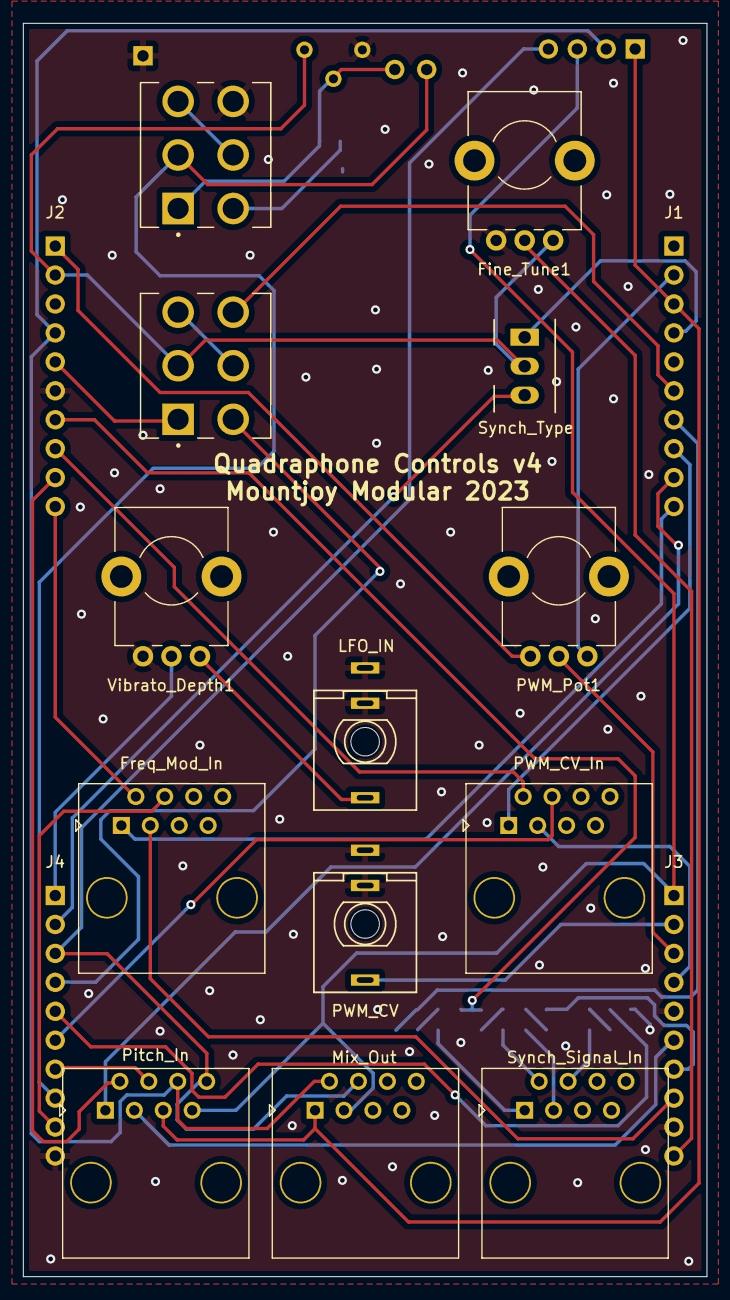
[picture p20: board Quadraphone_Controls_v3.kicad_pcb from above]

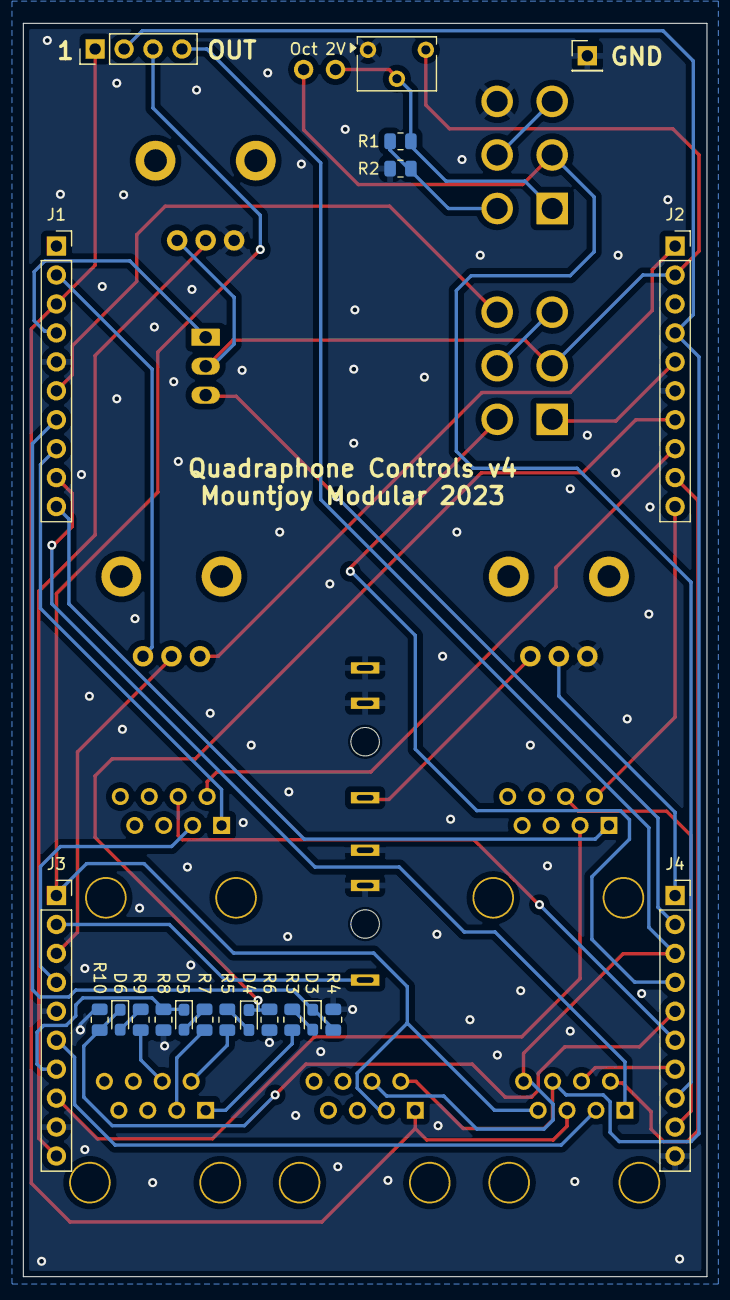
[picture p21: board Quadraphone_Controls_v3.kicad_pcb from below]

Board: 2 copper layers, 60.0 x 110.0 mm, 36 parts (21 on the bottom side), 47 nets.

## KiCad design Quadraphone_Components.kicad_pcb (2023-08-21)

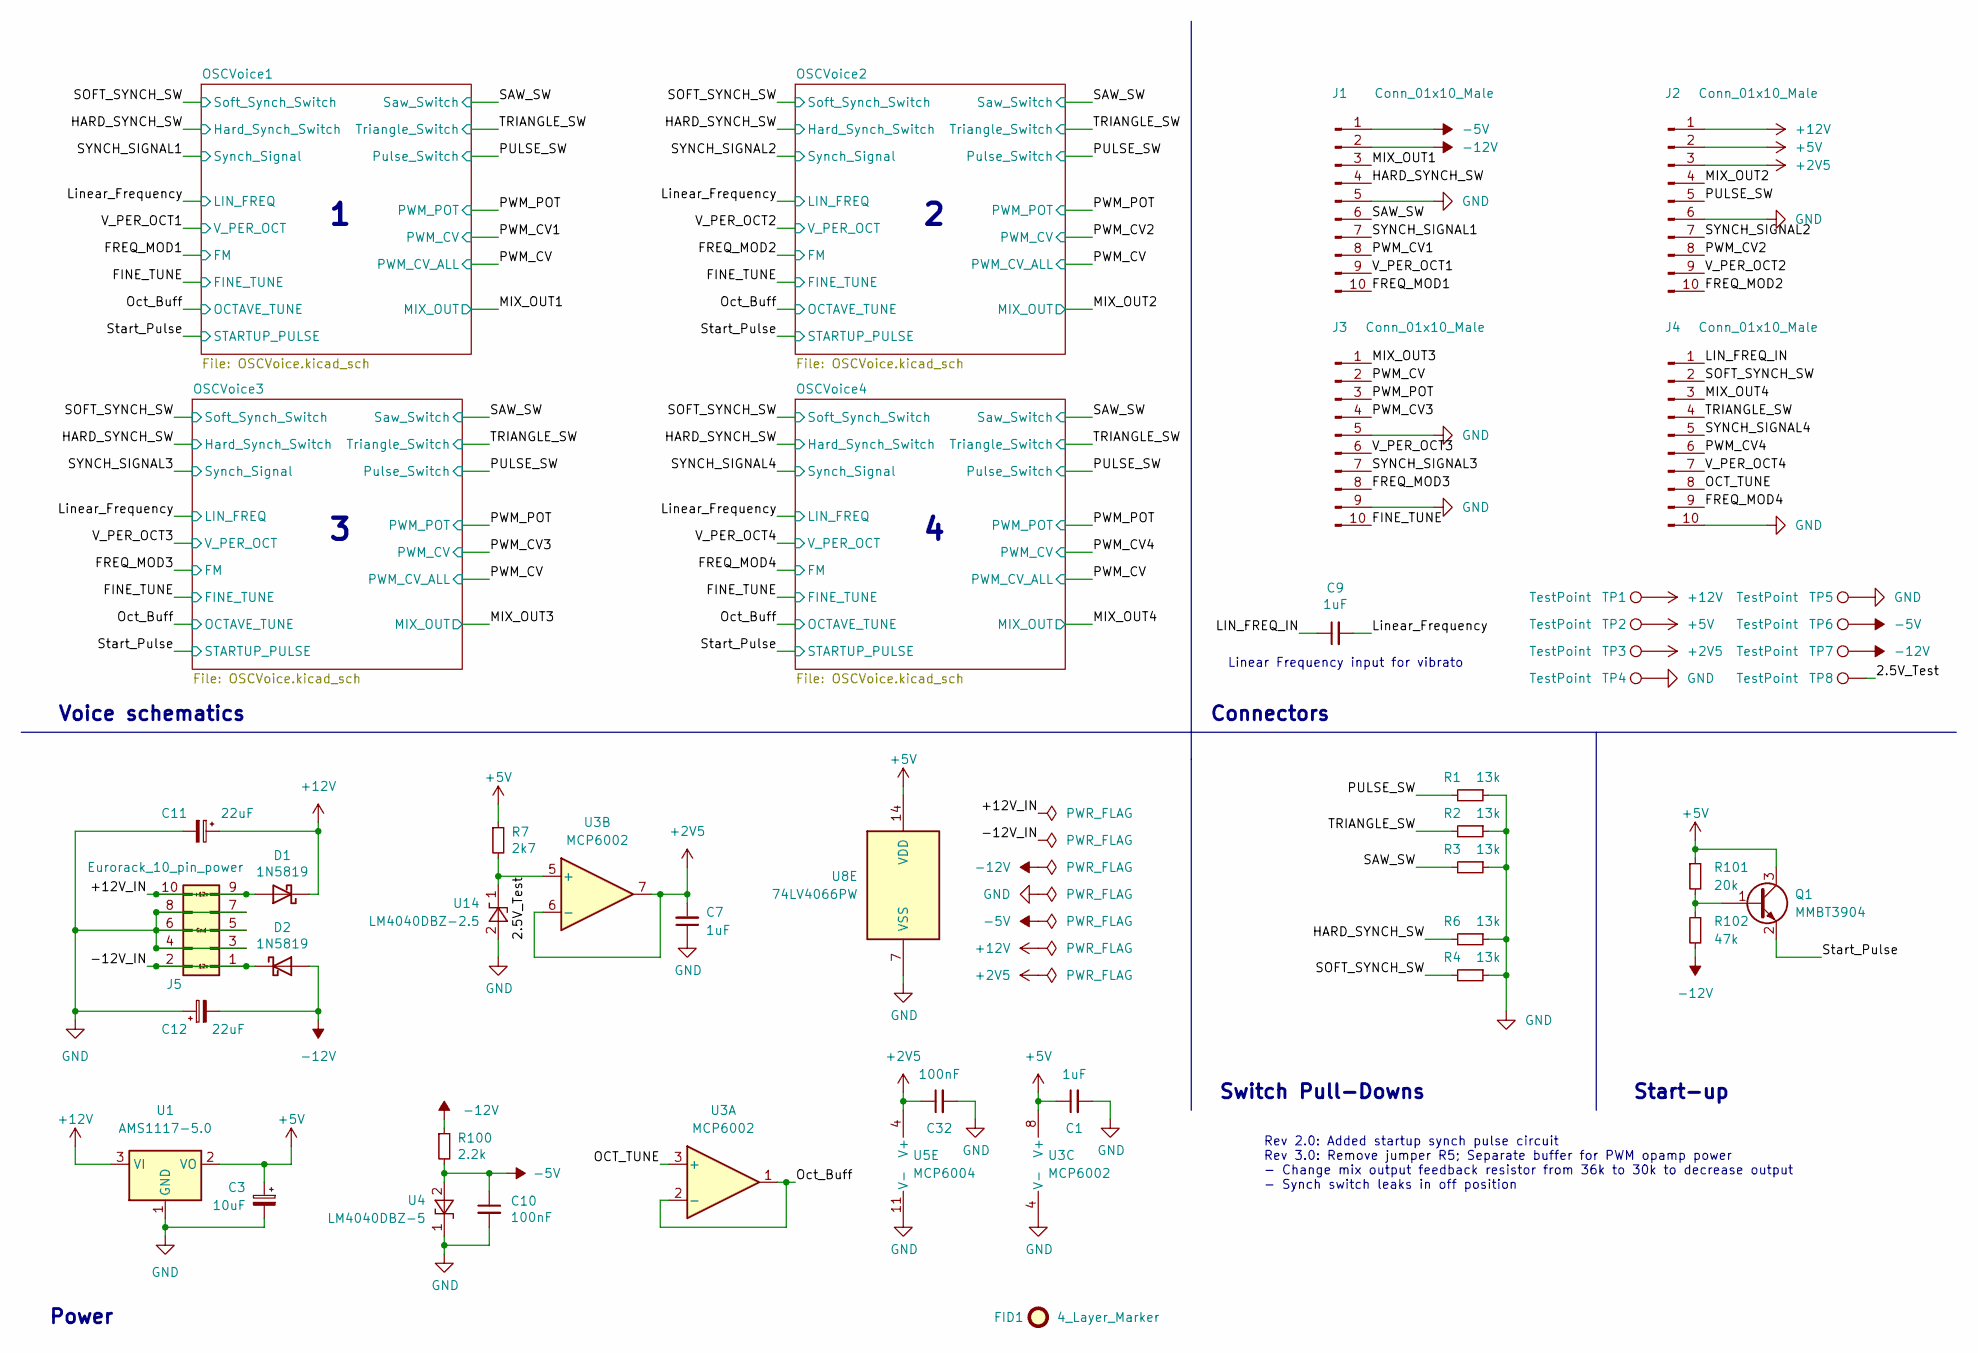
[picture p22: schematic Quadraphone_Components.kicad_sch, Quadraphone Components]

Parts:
C1, C7, C9: 1uF; C_0603_1608Metric_Pad1.08x0.95mm_HandSolder
C3: 10uF; CP_Elec_4x5.7
C10, C32: 100nF; C_0603_1608Metric_Pad1.08x0.95mm_HandSolder
C11, C12: 22uF; CP_Elec_4x5.8
D1, D2: 1N5819; D_SOD-123
FID1: 4_Layer_Marker; 4_Layer_Markers
J1, J2, J3, J4: Conn_01x10_Male; PinHeader_1x10_P2.54mm_Vertical
J5: Eurorack_10_pin_power; Eurorack_10_pin_header
Q1: MMBT3904; SOT-23
R1, R2, R3, R4, R6: 13k; R_0603_1608Metric
R7: 2k7; R_0603_1608Metric
R100: 2.2k; R_0603_1608Metric
R101: 20k; R_0603_1608Metric
R102: 47k; R_0603_1608Metric
TP1, TP2, TP3, TP4, TP5, TP6, TP7, TP8: TestPoint; 1.3mm_Test_Point
U1: AMS1117-5.0; SOT-223-3_TabPin2
U3: MCP6002; SOIC-8_3.9x4.9mm_P1.27mm
U4: LM4040DBZ-5; SOT-23
U5: MCP6004; SOIC-14_3.9x8.7mm_P1.27mm
U8: 74LV4066PW; TSSOP-14_4.4x5mm_P0.65mm
U14: LM4040DBZ-2.5; SOT-23

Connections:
+2V5: C7.2, C32.1, J2.3, TP3.1, U3.6 (-), U3.7, U5.4 (V+); also elsewhere on the board
+5V: C1.1, C3.1, J2.2, Q1.3 (C), R7.1, R101.1, TP2.1, U1.2 (VO), U3.8 (V+), U8.14 (VDD); also elsewhere on the board
+12V: C11.1, D1.1 (K), J2.1, TP1.1, U1.3 (VI); also elsewhere on the board
-5V: C10.1, J1.1, R100.2, TP6.1, U4.2 (A); also elsewhere on the board
-12V: C12.2, D2.2 (A), J1.2, R100.1, R102.2, TP7.1; also elsewhere on the board
/2.5V_Test: R7.2, TP8.1, U3.5 (+), U14.1 (K)
/+12V_IN: D1.2 (A), J5.9, J5.10
/-12V_IN: D2.1 (K), J5.1, J5.2
/FINE_TUNE: J3.10; also elsewhere on the board
/FREQ_MOD1: J1.10; also elsewhere on the board
/FREQ_MOD2: J2.10; also elsewhere on the board
/FREQ_MOD3: J3.8; also elsewhere on the board
/FREQ_MOD4: J4.9; also elsewhere on the board
/HARD_SYNCH_SW: J1.4, R6.2; also elsewhere on the board
/LIN_FREQ_IN: C9.1, J4.1
/Linear_Frequency: C9.2; also elsewhere on the board
/MIX_OUT1: J1.3; also elsewhere on the board
/MIX_OUT2: J2.4; also elsewhere on the board
/MIX_OUT3: J3.1; also elsewhere on the board
/MIX_OUT4: J4.3; also elsewhere on the board
/OCT_TUNE: J4.8, U3.3 (+)
/OSCVoice1/PWM_Control: U5.7; also elsewhere on the board
/OSCVoice1/PWM_Opamp_Mix: U5.6 (-); also elsewhere on the board
/OSCVoice1/Soft_Synch: U8.9; also elsewhere on the board
/OSCVoice2/PWM_Control: U5.1; also elsewhere on the board
/OSCVoice2/PWM_Opamp_Mix: U5.2 (-); also elsewhere on the board
/OSCVoice2/Soft_Synch: U8.3; also elsewhere on the board
/OSCVoice4/PWM_Control: U5.14; also elsewhere on the board
/OSCVoice4/PWM_Opamp_Mix: U5.13 (-); also elsewhere on the board
/OSCVoice4/Soft_Synch: U8.2; also elsewhere on the board
/Oct_Buff: U3.1, U3.2 (-); also elsewhere on the board
/PULSE_SW: J2.5, R1.2; also elsewhere on the board
/PWM_CV: J3.2; also elsewhere on the board
/PWM_CV1: J1.8; also elsewhere on the board
/PWM_CV2: J2.8; also elsewhere on the board
/PWM_CV3: J3.4; also elsewhere on the board
/PWM_CV4: J4.6; also elsewhere on the board
/PWM_POT: J3.3; also elsewhere on the board
/SAW_SW: J1.6, R3.2; also elsewhere on the board
/SOFT_SYNCH_SW: J4.2, R4.2, U8.5, U8.6, U8.13; also elsewhere on the board
/SYNCH_SIGNAL1: J1.7, U8.8; also elsewhere on the board
/SYNCH_SIGNAL2: J2.7, U8.4; also elsewhere on the board
/SYNCH_SIGNAL3: J3.7; also elsewhere on the board
/SYNCH_SIGNAL4: J4.5, U8.1; also elsewhere on the board
/Start_Pulse: Q1.2 (E); also elsewhere on the board
/TRIANGLE_SW: J4.4, R2.2; also elsewhere on the board
/V_PER_OCT1: J1.9; also elsewhere on the board
/V_PER_OCT2: J2.9; also elsewhere on the board
/V_PER_OCT3: J3.6; also elsewhere on the board
/V_PER_OCT4: J4.7; also elsewhere on the board
GND: C1.2, C3.2, C7.1, C10.2, C11.2, C12.1, C32.2, J1.5, J2.6, J3.5, J3.9, J4.10, J5.3, J5.4, J5.5, J5.6, J5.7, J5.8, R1.1, R2.1, R3.1, R4.1, R6.1, TP4.1, TP5.1, U1.1 (GND), U3.4 (V-), U4.1 (K), U5.3 (+), U5.5 (+), U5.11 (V-), U5.12 (+), U8.7 (VSS), U14.2 (A); also elsewhere on the board
unnamed: Q1.1 (B), R101.2, R102.1

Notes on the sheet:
Rev 2.0: Added startup synch pulse circuit Rev 3.0: Remove jumper R5; Separate buffer for PWM opamp power - Change mix output feedback resistor from 36k to 30k to decrease output - Synch switch leaks in off position
Linear Frequency input for vibrato
Start-up
Switch Pull-Downs
Connectors
Power
Voice schematics

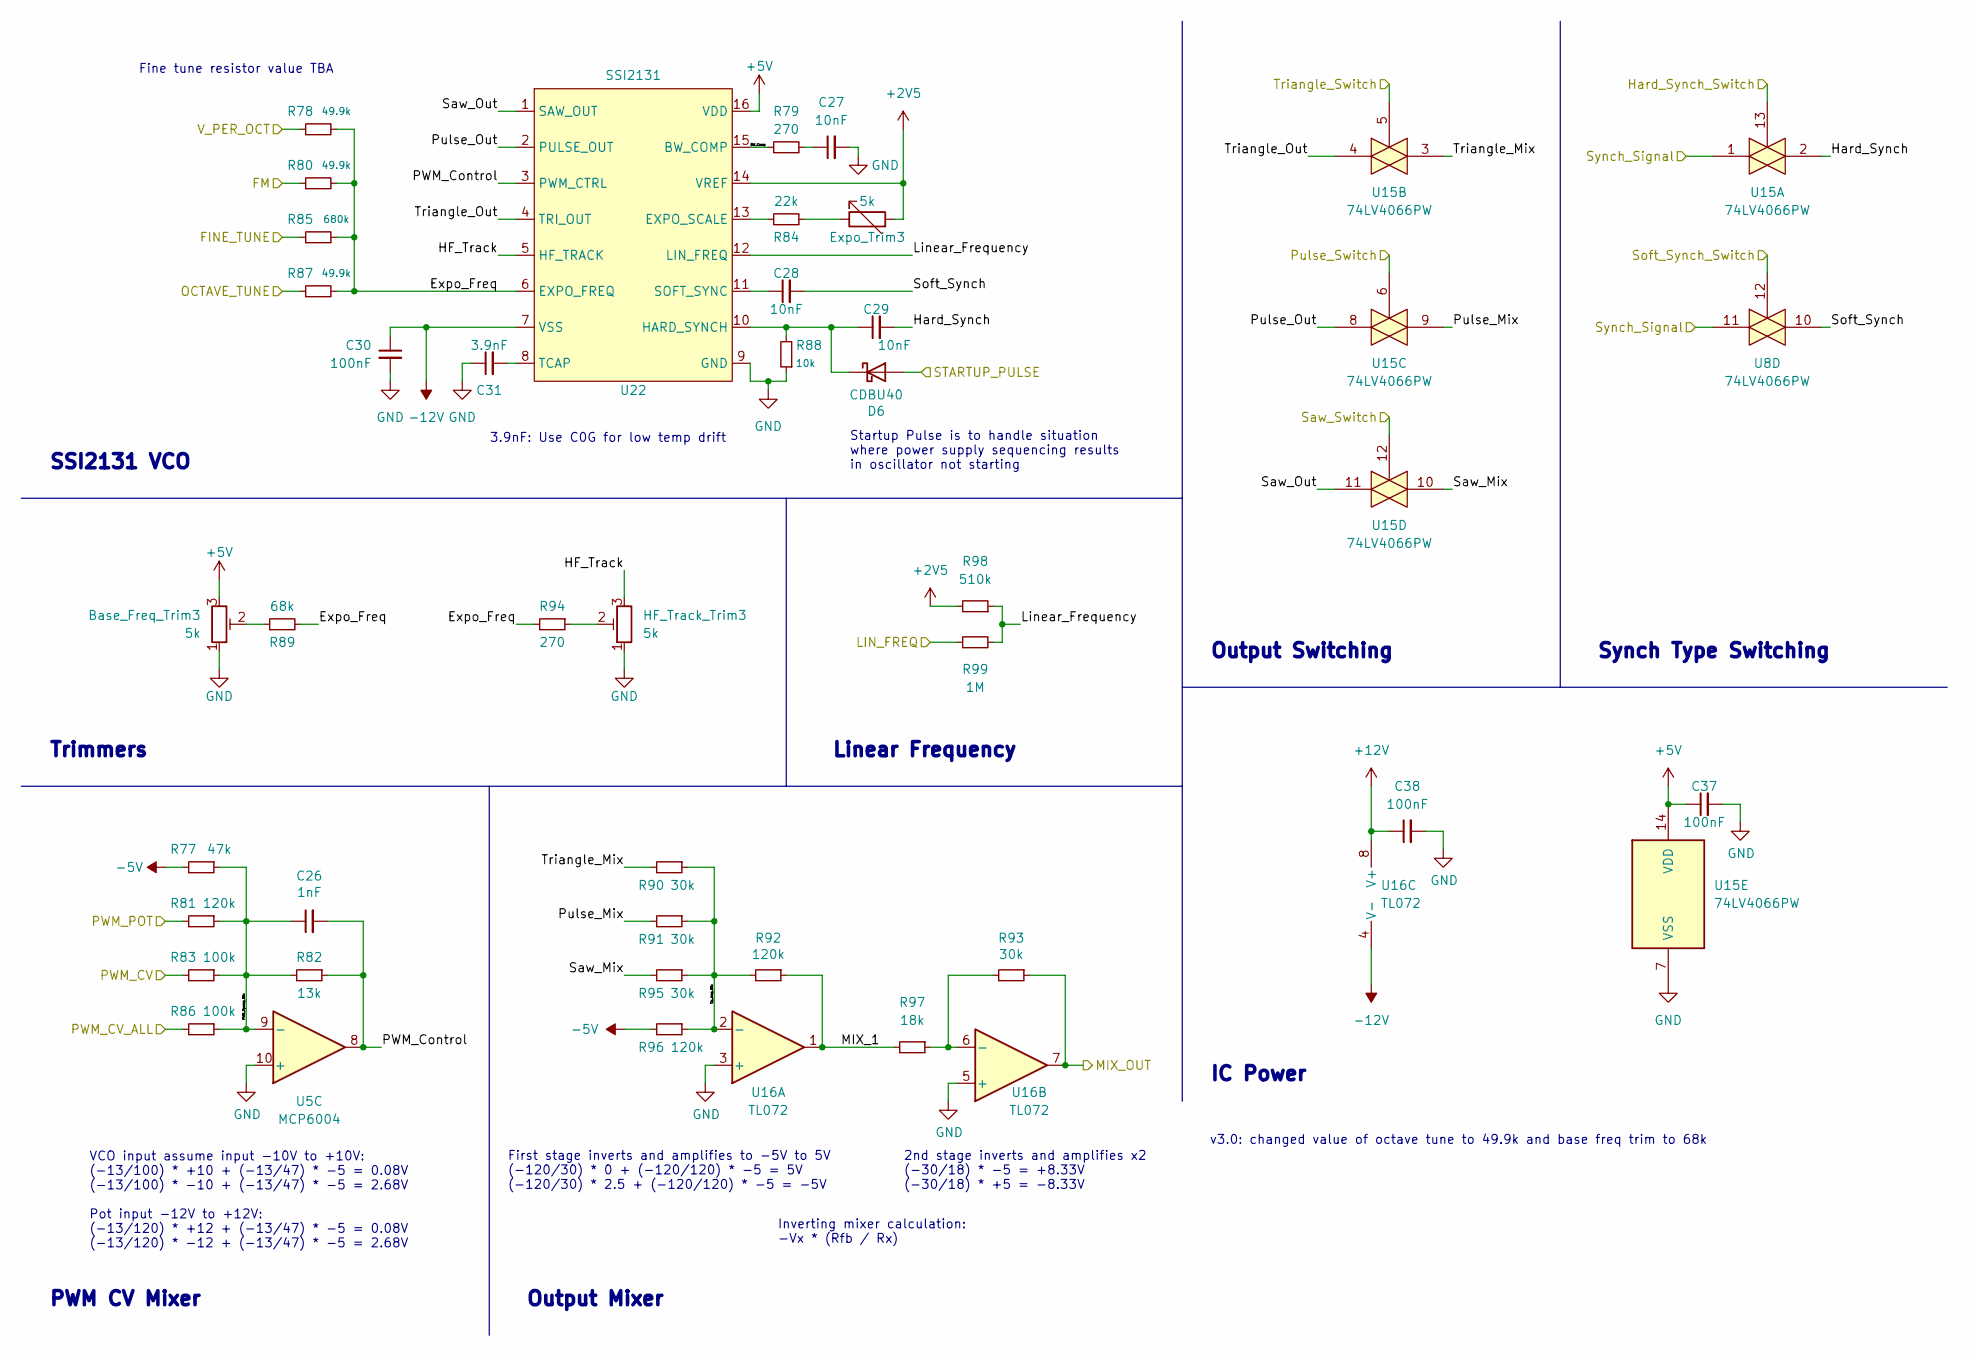
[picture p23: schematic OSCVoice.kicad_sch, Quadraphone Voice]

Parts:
Base_Freq_Trim3: 5k; Potentiometer_Bourns_3266W_Vertical
C26: 1nF; C_0603_1608Metric_Pad1.08x0.95mm_HandSolder
C27, C28, C29: 10nF; C_0603_1608Metric_Pad1.08x0.95mm_HandSolder
C30, C37, C38: 100nF; C_0603_1608Metric_Pad1.08x0.95mm_HandSolder
C31: 3.9nF; C_0603_1608Metric_Pad1.08x0.95mm_HandSolder
D6: CDBU40; D_0603_1608Metric
Expo_Trim3: 5k; Potentiometer_Bourns_3266W_Vertical
HF_Track_Trim3: 5k; Potentiometer_Bourns_3266W_Vertical
R77: 47k; R_0603_1608Metric
R78, R80, R87: 49.9k; R_0603_1608Metric
R79, R94: 270; R_0603_1608Metric
R81, R92, R96: 120k; R_0603_1608Metric
R82: 13k; R_0603_1608Metric
R83, R86: 100k; R_0603_1608Metric
R84: 22k; R_0603_1608Metric
R85: 680k; R_0603_1608Metric
R88: 10k; R_0603_1608Metric
R89: 68k; R_0603_1608Metric
R90, R91, R93, R95: 30k; R_0603_1608Metric
R97: 18k; R_0603_1608Metric
R98: 510k; R_0603_1608Metric
R99: 1M; R_0603_1608Metric
U5: MCP6004; SOIC-14_3.9x8.7mm_P1.27mm
U8, U15: 74LV4066PW; TSSOP-14_4.4x5mm_P0.65mm
U16: TL072; SOIC-8_3.9x4.9mm_P1.27mm
U22: SSI2131; SOIC-16_3.9x9.9mm_P1.27mm

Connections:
+2V5: Expo_Trim3.2, R98.2, U22.14 (VREF); also elsewhere on the board
+5V: Base_Freq_Trim3.3, C37.1, U15.14 (VDD), U22.16 (VDD); also elsewhere on the board
+12V: C38.1, U16.8 (V+); also elsewhere on the board
-5V: R77.2, R96.2; also elsewhere on the board
-12V: C30.1, U16.4 (V-), U22.7 (VSS); also elsewhere on the board
/FINE_TUNE: R85.1; also elsewhere on the board
/FREQ_MOD3: R80.1; also elsewhere on the board
/HARD_SYNCH_SW: U15.13; also elsewhere on the board
/Linear_Frequency: R99.1; also elsewhere on the board
/MIX_OUT3: R93.1, U16.7; also elsewhere on the board
/OSCVoice1/PWM_Control: U5.7; also elsewhere on the board
/OSCVoice1/PWM_Opamp_Mix: U5.6 (-); also elsewhere on the board
/OSCVoice1/Soft_Synch: U8.9; also elsewhere on the board
/OSCVoice2/PWM_Control: U5.1; also elsewhere on the board
/OSCVoice2/PWM_Opamp_Mix: U5.2 (-); also elsewhere on the board
/OSCVoice2/Soft_Synch: U8.3; also elsewhere on the board
/OSCVoice3/BW_Comp: R79.1, U22.15 (BW_COMP)
/OSCVoice3/Expo_Freq: R78.2, R80.2, R85.2, R87.2, R89.2, R94.2, U22.6 (EXPO_FREQ)
/OSCVoice3/HF_Track: HF_Track_Trim3.3, U22.5 (HF_TRACK)
/OSCVoice3/Hard_Synch: C29.2, U15.2
/OSCVoice3/Linear_Frequency: R98.1, R99.2, U22.12 (LIN_FREQ)
/OSCVoice3/MIX_1: R92.1, R97.2, U16.1
/OSCVoice3/Op_Amp_Mix: R90.1, R91.1, R92.2, R95.1, R96.1, U16.2 (-)
/OSCVoice3/PWM_Control: C26.2, R82.1, U5.8, U22.3 (PWM_CTRL)
/OSCVoice3/PWM_Opamp_Mix: C26.1, R77.1, R81.1, R82.2, R83.1, R86.1, U5.9 (-)
/OSCVoice3/Pulse_Mix: R91.2, U15.9
/OSCVoice3/Pulse_Out: U15.8, U22.2 (PULSE_OUT)
/OSCVoice3/Saw_Mix: R95.2, U15.10
/OSCVoice3/Saw_Out: U15.11, U22.1 (SAW_OUT)
/OSCVoice3/Soft_Synch: C28.2, U8.10
/OSCVoice3/Triangle_Mix: R90.2, U15.3
/OSCVoice3/Triangle_Out: U15.4, U22.4 (TRI_OUT)
/OSCVoice4/PWM_Control: U5.14; also elsewhere on the board
/OSCVoice4/PWM_Opamp_Mix: U5.13 (-); also elsewhere on the board
/OSCVoice4/Soft_Synch: U8.2; also elsewhere on the board
/Oct_Buff: R87.1; also elsewhere on the board
/PULSE_SW: U15.6; also elsewhere on the board
/PWM_CV: R86.2; also elsewhere on the board
/PWM_CV3: R83.2; also elsewhere on the board
/PWM_POT: R81.2; also elsewhere on the board
/SAW_SW: U15.12; also elsewhere on the board
/SOFT_SYNCH_SW: U8.5, U8.6, U8.12, U8.13; also elsewhere on the board
/SYNCH_SIGNAL1: U8.8; also elsewhere on the board
/SYNCH_SIGNAL2: U8.4; also elsewhere on the board
/SYNCH_SIGNAL3: U8.11, U15.1; also elsewhere on the board
/SYNCH_SIGNAL4: U8.1; also elsewhere on the board
/Start_Pulse: D6.2 (A); also elsewhere on the board
/TRIANGLE_SW: U15.5; also elsewhere on the board
/V_PER_OCT3: R78.1; also elsewhere on the board
GND: Base_Freq_Trim3.1, C27.2, C30.2, C31.1, C37.2, C38.2, HF_Track_Trim3.1, R88.1, U5.3 (+), U5.5 (+), U5.10 (+), U5.12 (+), U15.7 (VSS), U16.3 (+), U16.5 (+), U22.9 (GND); also elsewhere on the board
unnamed: Base_Freq_Trim3.2, R89.1
unnamed: C27.1, R79.2
unnamed: C29.1, D6.1 (K), R88.2, U22.10 (HARD_SYNCH)
unnamed: Expo_Trim3.1, R84.2
unnamed: HF_Track_Trim3.2, R94.1
unnamed: R93.2, R97.1, U16.6 (-)
unnamed: R84.1, U22.13 (EXPO_SCALE)
unnamed: C28.1, U22.11 (SOFT_SYNC)
unnamed: C31.2, U22.8 (TCAP)

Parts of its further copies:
Base_Freq_Trim1, Base_Freq_Trim2, Base_Freq_Trim4: 5k; Potentiometer_Bourns_3266W_Vertical
C4, C5, C6, C15, C16, C17, C21, C22, C23: 10nF; C_0603_1608Metric_Pad1.08x0.95mm_HandSolder
C8, C19, C25: 3.9nF; C_0603_1608Metric_Pad1.08x0.95mm_HandSolder
C13, C14, C20: 1nF; C_0603_1608Metric_Pad1.08x0.95mm_HandSolder
C18, C24, C33, C34, C35, C36, C39, C40, C41: 100nF; C_0603_1608Metric_Pad1.08x0.95mm_HandSolder
D3, D4, D5: CDBU40; D_0603_1608Metric
Expo_Trim1, Expo_Trim2, Expo_Trim4: 5k; Potentiometer_Bourns_3266W_Vertical
HF_Track_Trim1, HF_Track_Trim2, HF_Track_Trim4: 5k; Potentiometer_Bourns_3266W_Vertical
R8, R38, R61: 22k; R_0603_1608Metric
R9, R42, R65: 10k; R_0603_1608Metric
R10, R16, R33, R48, R56, R71: 270; R_0603_1608Metric
R11, R31, R54: 47k; R_0603_1608Metric
R12, R21, R28, R35, R46, R50, R58, R69, R73: 120k; R_0603_1608Metric
R13, R15, R25, R40, R60, R63: 100k; R_0603_1608Metric
R14, R36, R59: 13k; R_0603_1608Metric
R17, R39, R62: 680k; R_0603_1608Metric
R18, R22, R32, R34, R37, R41, R55, R57, R64: 49.9k; R_0603_1608Metric
R19, R20, R26, R27, R44, R45, R47, R49, R67, R68, R70, R72: 30k; R_0603_1608Metric
R23, R43, R66: 68k; R_0603_1608Metric
R24, R52, R75: 510k; R_0603_1608Metric
R29, R51, R74: 18k; R_0603_1608Metric
R30, R53, R76: 1M; R_0603_1608Metric
U6, U7, U11: 74LV4066PW; TSSOP-14_4.4x5mm_P0.65mm
U9, U12, U17: SSI2131; SOIC-16_3.9x9.9mm_P1.27mm
U10, U13, U18: TL072; SOIC-8_3.9x4.9mm_P1.27mm

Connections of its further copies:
+2V5: Expo_Trim1.2, Expo_Trim2.2, Expo_Trim4.2, R24.2, R52.2, R75.2, U9.14 (VREF), U12.14 (VREF), U17.14 (VREF); also elsewhere on the board
+5V: Base_Freq_Trim1.3, Base_Freq_Trim2.3, Base_Freq_Trim4.3, C33.1, C35.1, C39.1, U6.14 (VDD), U7.14 (VDD), U9.16 (VDD), U11.14 (VDD), U12.16 (VDD), U17.16 (VDD); also elsewhere on the board
+12V: C34.1, C36.1, C40.1, U10.8 (V+), U13.8 (V+), U18.8 (V+); also elsewhere on the board
-5V: R11.2, R28.2, R31.2, R50.2, R54.2, R73.2; also elsewhere on the board
-12V: C18.1, C24.1, C41.1, U9.7 (VSS), U10.4 (V-), U12.7 (VSS), U13.4 (V-), U17.7 (VSS), U18.4 (V-); also elsewhere on the board
/FINE_TUNE: R17.1, R39.1, R62.1; also elsewhere on the board
/FREQ_MOD1: R18.1; also elsewhere on the board
/FREQ_MOD2: R34.1; also elsewhere on the board
/FREQ_MOD4: R57.1; also elsewhere on the board
/HARD_SYNCH_SW: U6.13, U7.13, U11.13; also elsewhere on the board
/Linear_Frequency: R30.1, R53.1, R76.1; also elsewhere on the board
/MIX_OUT1: R26.1, U10.7; also elsewhere on the board
/MIX_OUT2: R47.1, U13.7; also elsewhere on the board
/MIX_OUT4: R70.1, U18.7; also elsewhere on the board
/OSCVoice1/BW_Comp: R10.1, U9.15 (BW_COMP)
/OSCVoice1/Expo_Freq: R16.2, R17.2, R18.2, R22.2, R23.2, R37.2, U9.6 (EXPO_FREQ)
/OSCVoice1/HF_Track: HF_Track_Trim1.3, U9.5 (HF_TRACK)
/OSCVoice1/Hard_Synch: C6.2, U6.2
/OSCVoice1/Linear_Frequency: R24.1, R30.2, U9.12 (LIN_FREQ)
/OSCVoice1/MIX_1: R21.1, R29.2, U10.1
/OSCVoice1/Op_Amp_Mix: R19.1, R20.1, R21.2, R27.1, R28.1, U10.2 (-)
/OSCVoice1/PWM_Control: C13.2, R14.1, U9.3 (PWM_CTRL); also elsewhere on the board
/OSCVoice1/PWM_Opamp_Mix: C13.1, R11.1, R12.1, R14.2, R15.1, R25.1; also elsewhere on the board
/OSCVoice1/Pulse_Mix: R20.2, U6.9
/OSCVoice1/Pulse_Out: U6.8, U9.2 (PULSE_OUT)
/OSCVoice1/Saw_Mix: R27.2, U6.10
/OSCVoice1/Saw_Out: U6.11, U9.1 (SAW_OUT)
/OSCVoice1/Soft_Synch: C5.2; also elsewhere on the board
/OSCVoice1/Triangle_Mix: R19.2, U6.3
/OSCVoice1/Triangle_Out: U6.4, U9.4 (TRI_OUT)
/OSCVoice2/BW_Comp: R33.1, U12.15 (BW_COMP)
/OSCVoice2/Expo_Freq: R32.2, R34.2, R39.2, R41.2, R43.2, R48.2, U12.6 (EXPO_FREQ)
/OSCVoice2/HF_Track: HF_Track_Trim2.3, U12.5 (HF_TRACK)
/OSCVoice2/Hard_Synch: C17.2, U7.2
/OSCVoice2/Linear_Frequency: R52.1, R53.2, U12.12 (LIN_FREQ)
/OSCVoice2/MIX_1: R46.1, R51.2, U13.1
/OSCVoice2/Op_Amp_Mix: R44.1, R45.1, R46.2, R49.1, R50.1, U13.2 (-)
/OSCVoice2/PWM_Control: C14.2, R36.1, U12.3 (PWM_CTRL); also elsewhere on the board
/OSCVoice2/PWM_Opamp_Mix: C14.1, R31.1, R35.1, R36.2, R40.1, R60.1; also elsewhere on the board
/OSCVoice2/Pulse_Mix: R45.2, U7.9
/OSCVoice2/Pulse_Out: U7.8, U12.2 (PULSE_OUT)
/OSCVoice2/Saw_Mix: R49.2, U7.10
/OSCVoice2/Saw_Out: U7.11, U12.1 (SAW_OUT)
/OSCVoice2/Soft_Synch: C16.2; also elsewhere on the board
/OSCVoice2/Triangle_Mix: R44.2, U7.3
/OSCVoice2/Triangle_Out: U7.4, U12.4 (TRI_OUT)
/OSCVoice4/BW_Comp: R56.1, U17.15 (BW_COMP)
/OSCVoice4/Expo_Freq: R55.2, R57.2, R62.2, R64.2, R66.2, R71.2, U17.6 (EXPO_FREQ)
/OSCVoice4/HF_Track: HF_Track_Trim4.3, U17.5 (HF_TRACK)
/OSCVoice4/Hard_Synch: C23.2, U11.2
/OSCVoice4/Linear_Frequency: R75.1, R76.2, U17.12 (LIN_FREQ)
/OSCVoice4/MIX_1: R69.1, R74.2, U18.1
/OSCVoice4/Op_Amp_Mix: R67.1, R68.1, R69.2, R72.1, R73.1, U18.2 (-)
/OSCVoice4/PWM_Control: C20.2, R59.1, U17.3 (PWM_CTRL); also elsewhere on the board
/OSCVoice4/PWM_Opamp_Mix: C20.1, R13.1, R54.1, R58.1, R59.2, R63.1; also elsewhere on the board
/OSCVoice4/Pulse_Mix: R68.2, U11.9
/OSCVoice4/Pulse_Out: U11.8, U17.2 (PULSE_OUT)
/OSCVoice4/Saw_Mix: R72.2, U11.10
/OSCVoice4/Saw_Out: U11.11, U17.1 (SAW_OUT)
/OSCVoice4/Soft_Synch: C22.2; also elsewhere on the board
/OSCVoice4/Triangle_Mix: R67.2, U11.3
/OSCVoice4/Triangle_Out: U11.4, U17.4 (TRI_OUT)
/Oct_Buff: R22.1, R41.1, R64.1; also elsewhere on the board
/PULSE_SW: U6.6, U7.6, U11.6; also elsewhere on the board
/PWM_CV: R15.2, R40.2, R63.2; also elsewhere on the board
/PWM_CV1: R25.2; also elsewhere on the board
/PWM_CV2: R60.2; also elsewhere on the board
/PWM_CV4: R13.2; also elsewhere on the board
/PWM_POT: R12.2, R35.2, R58.2; also elsewhere on the board
/SAW_SW: U6.12, U7.12, U11.12; also elsewhere on the board
/SYNCH_SIGNAL1: U6.1; also elsewhere on the board
/SYNCH_SIGNAL2: U7.1; also elsewhere on the board
/SYNCH_SIGNAL4: U11.1; also elsewhere on the board
/Start_Pulse: D3.2 (A), D4.2 (A), D5.2 (A); also elsewhere on the board
/TRIANGLE_SW: U6.5, U7.5, U11.5; also elsewhere on the board
/V_PER_OCT1: R37.1; also elsewhere on the board
/V_PER_OCT2: R32.1; also elsewhere on the board
/V_PER_OCT4: R55.1; also elsewhere on the board
GND: Base_Freq_Trim1.1, Base_Freq_Trim2.1, Base_Freq_Trim4.1, C4.2, C8.1, C15.2, C18.2, C19.1, C21.2, C24.2, C25.1, C33.2, C34.2, C35.2, C36.2, C39.2, C40.2, C41.2, HF_Track_Trim1.1, HF_Track_Trim2.1, HF_Track_Trim4.1, R9.1, R42.1, R65.1, U6.7 (VSS), U7.7 (VSS), U9.9 (GND), U10.3 (+), U10.5 (+), U11.7 (VSS), U12.9 (GND), U13.3 (+), U13.5 (+), U17.9 (GND), U18.3 (+), U18.5 (+); also elsewhere on the board
unnamed: Base_Freq_Trim1.2, R23.1
unnamed: Base_Freq_Trim2.2, R43.1
unnamed: Base_Freq_Trim4.2, R66.1
unnamed: C4.1, R10.2
unnamed: C15.1, R33.2
unnamed: C21.1, R56.2
unnamed: C6.1, D3.1 (K), R9.2, U9.10 (HARD_SYNCH)
unnamed: C17.1, D4.1 (K), R42.2, U12.10 (HARD_SYNCH)
unnamed: C23.1, D5.1 (K), R65.2, U17.10 (HARD_SYNCH)
unnamed: Expo_Trim1.1, R8.2
unnamed: Expo_Trim2.1, R38.2
unnamed: Expo_Trim4.1, R61.2
unnamed: HF_Track_Trim1.2, R16.1
unnamed: HF_Track_Trim2.2, R48.1
unnamed: HF_Track_Trim4.2, R71.1
unnamed: R8.1, U9.13 (EXPO_SCALE)
unnamed: C5.1, U9.11 (SOFT_SYNC)
unnamed: C8.2, U9.8 (TCAP)
unnamed: R26.2, R29.1, U10.6 (-)
unnamed: R38.1, U12.13 (EXPO_SCALE)
unnamed: C16.1, U12.11 (SOFT_SYNC)
unnamed: C19.2, U12.8 (TCAP)
unnamed: R47.2, R51.1, U13.6 (-)
unnamed: R61.1, U17.13 (EXPO_SCALE)
unnamed: C22.1, U17.11 (SOFT_SYNC)
unnamed: C25.2, U17.8 (TCAP)
unnamed: R70.2, R74.1, U18.6 (-)

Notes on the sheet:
First stage inverts and amplifies to -5V to 5V (-120/30) * 0 + (-120/120) * -5 = 5V (-120/30) * 2.5 + (-120/120) * -5 = -5V
Startup Pulse is to handle situation where power supply sequencing results in oscillator not starting
Fine tune resistor value TBA
PWM CV Mixer
Synch Type Switching
Inverting mixer calculation: -Vx * (Rfb / Rx)
SSI2131 VCO
Linear Frequency
VCO input assume input -10V to +10V: (-13/100) * +10 + (-13/47) * -5 = 0.08V (-13/100) * -10 + (-13/47) * -5 = 2.68V Pot input -12V to +12V: (-13/120) * +12 + (-13/47) * -5 = 0.08V (-13/120) * -12 + (-13/47) * -5 = 2.68V
Trimmers
Output Mixer
v3.0: changed value of octave tune to 49.9k and base freq trim to 68k
3.9nF: Use C0G for low temp drift
IC Power
2nd stage inverts and amplifies x2 (-30/18) * -5 = +8.33V (-30/18) * +5 = -8.33V
Output Switching

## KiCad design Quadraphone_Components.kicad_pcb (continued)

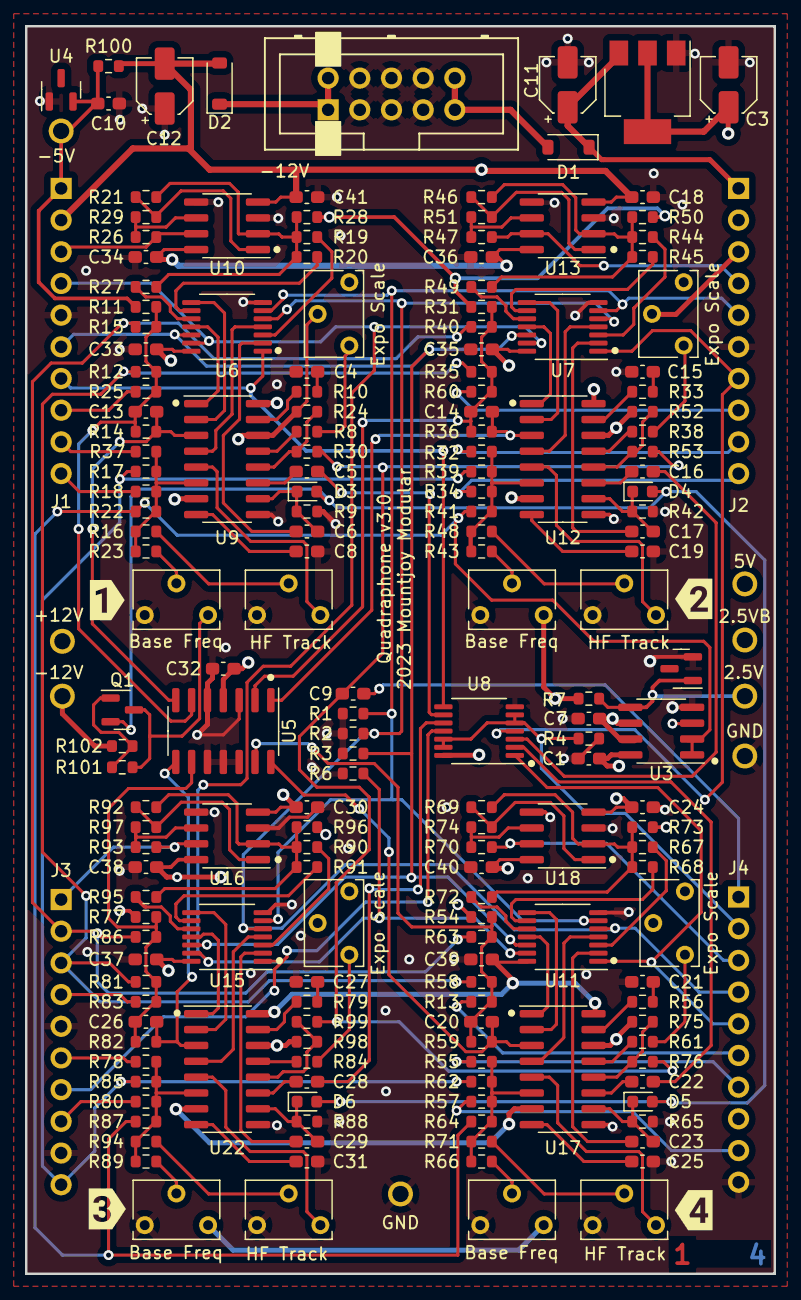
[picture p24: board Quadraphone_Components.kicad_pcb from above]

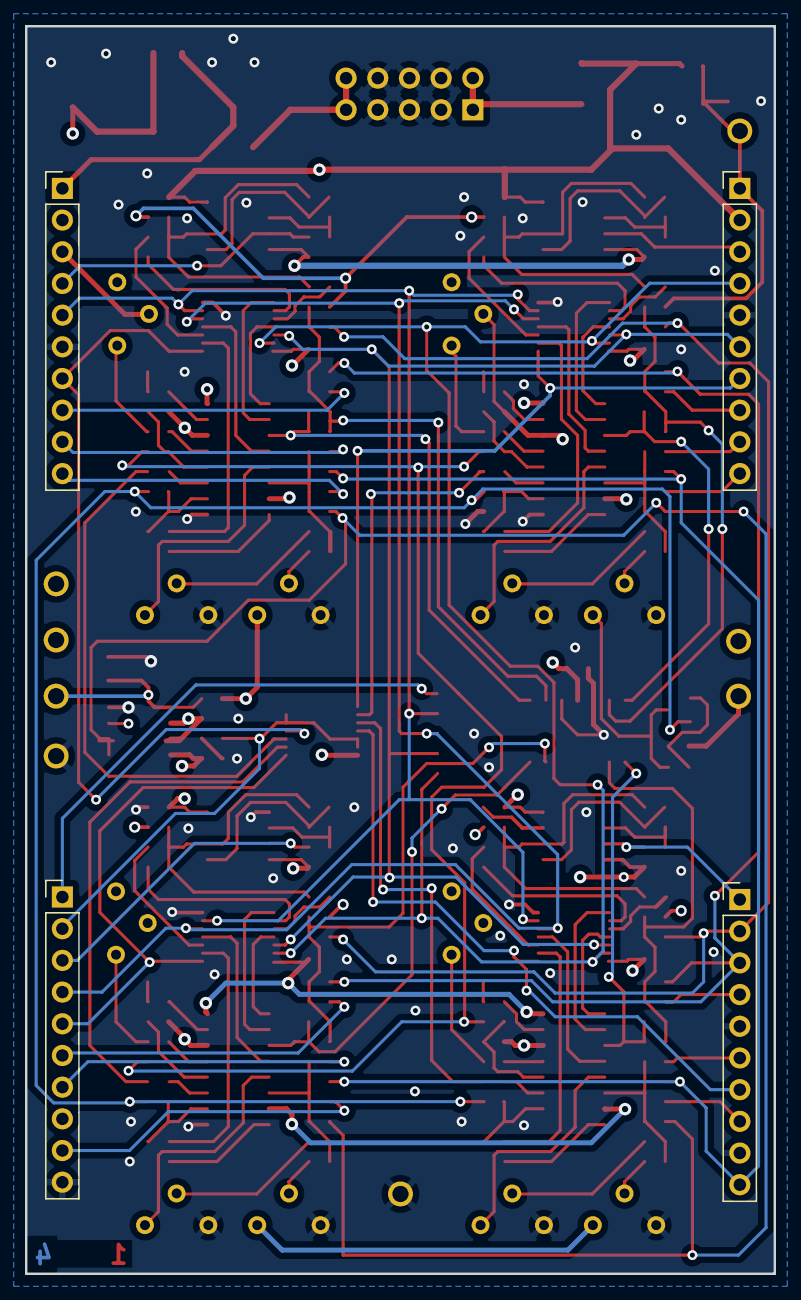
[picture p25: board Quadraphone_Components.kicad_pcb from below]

Board: 4 copper layers, 60.0 x 100.0 mm, 196 parts (4 on the bottom side), 143 nets.

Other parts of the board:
kibuzzard-63D3EB0F: G***; kibuzzard-63D3EB0F
kibuzzard-63D3EB2D: G***; kibuzzard-63D3EB2D
kibuzzard-63D3EB3D: G***; kibuzzard-63D3EB3D
kibuzzard-63D3EB53: G***; kibuzzard-63D3EB53

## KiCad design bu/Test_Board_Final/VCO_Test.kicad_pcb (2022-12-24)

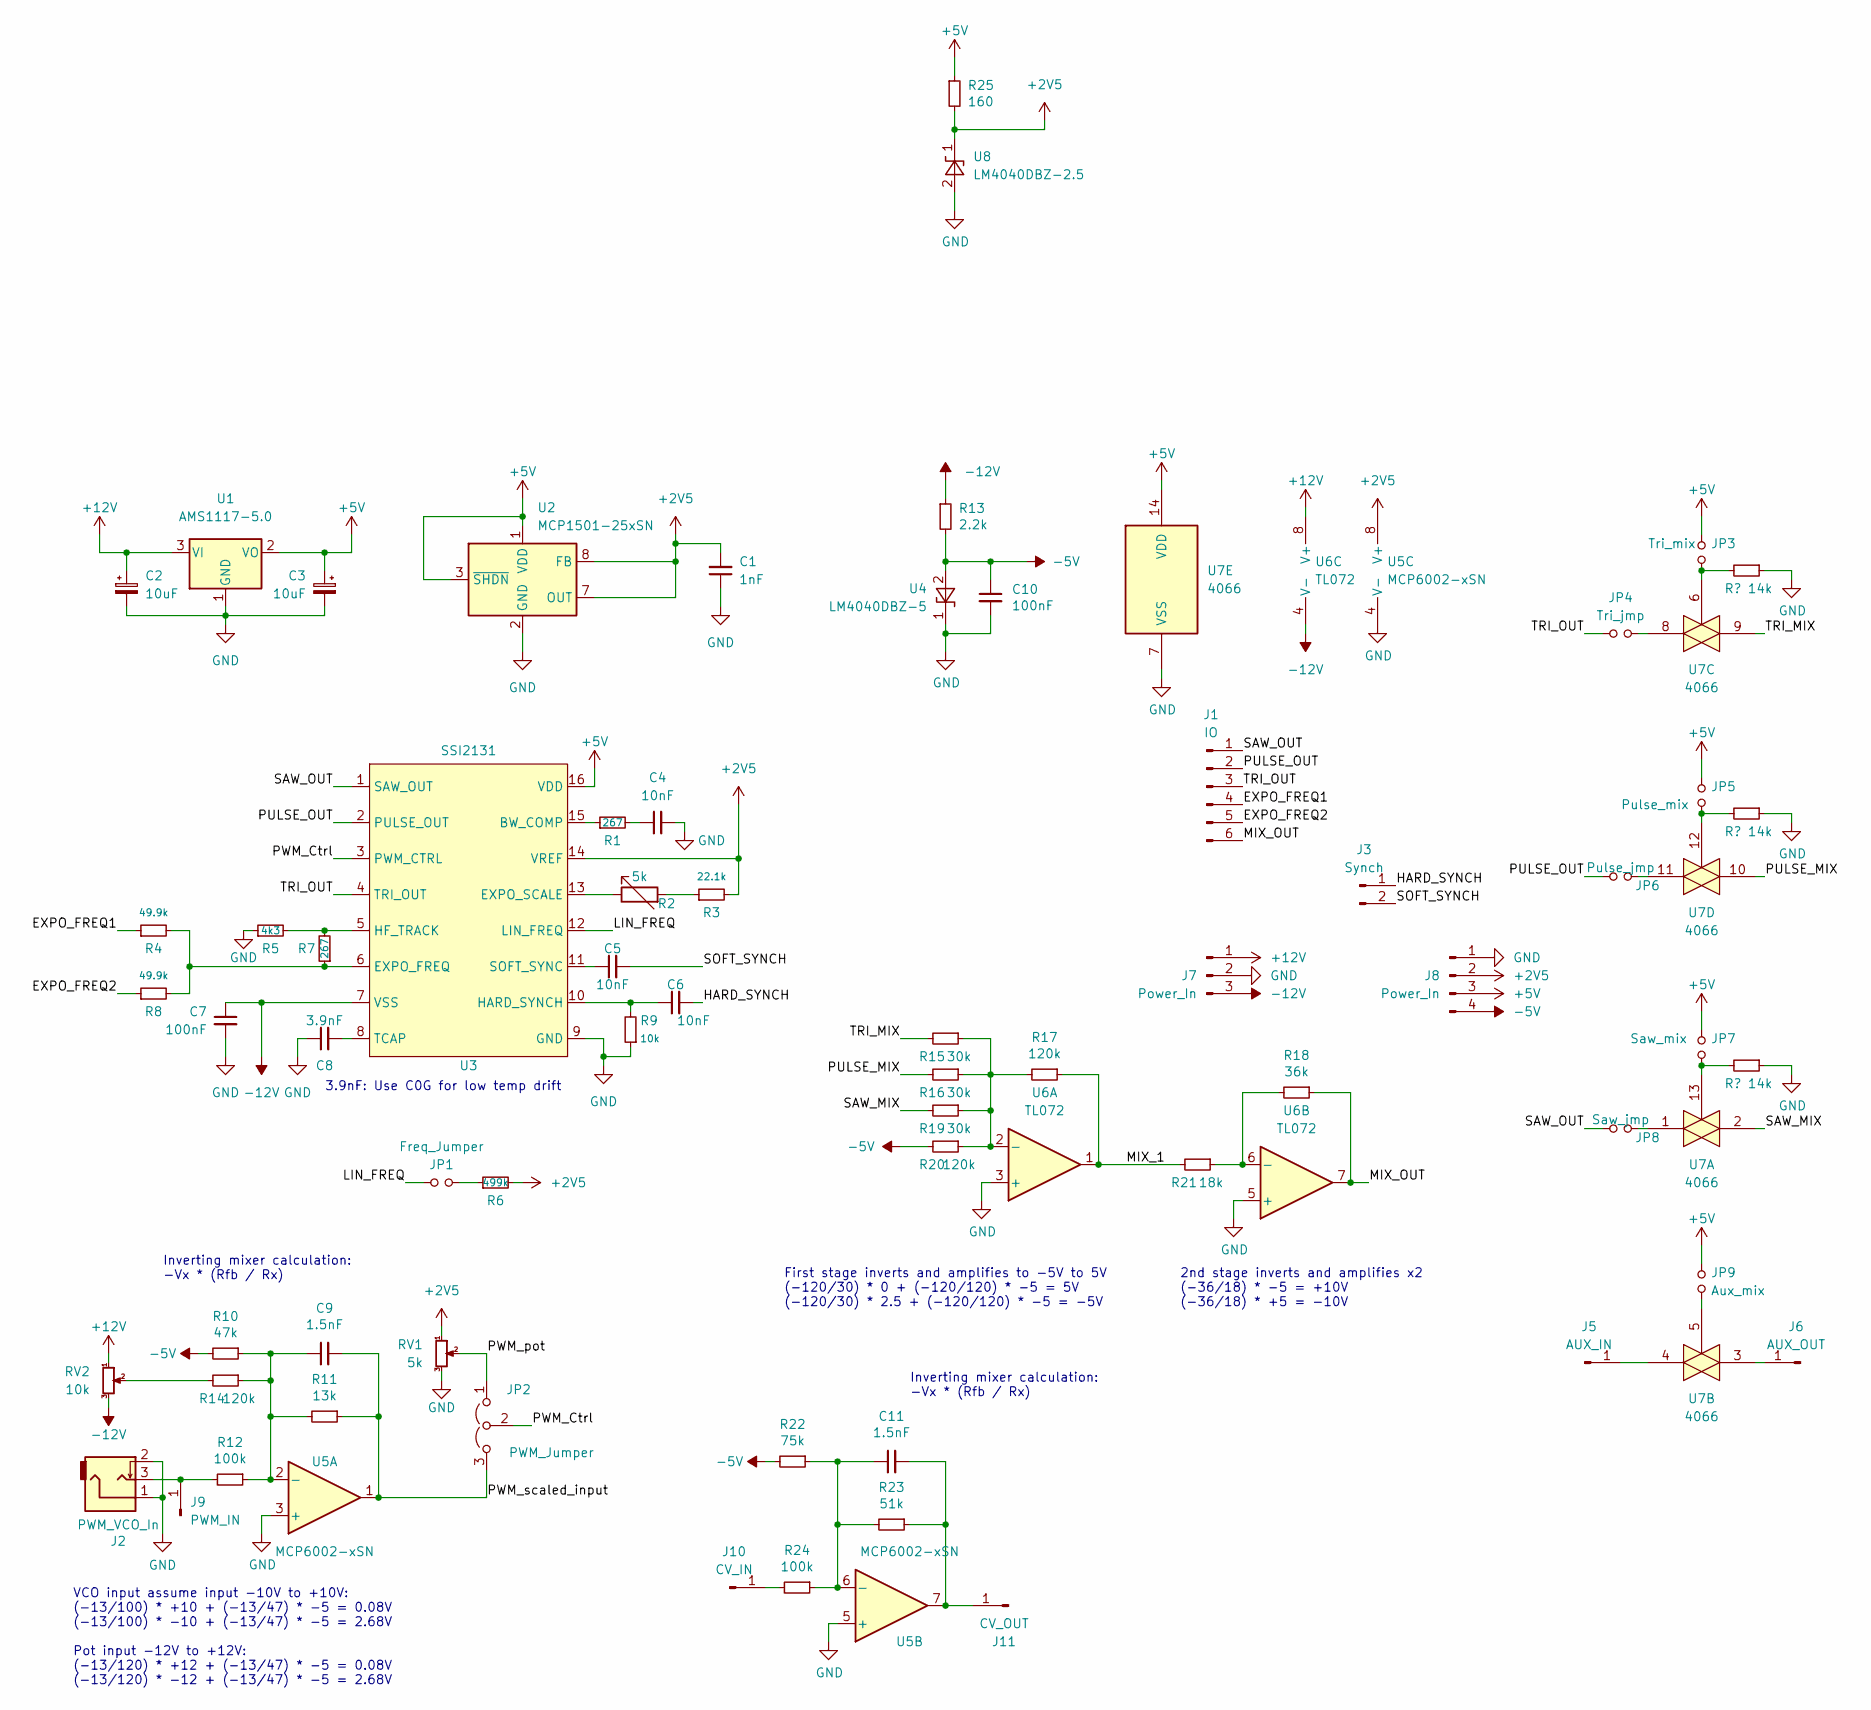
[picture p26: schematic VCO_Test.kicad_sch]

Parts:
C1: 1nF; C_0805_2012Metric
C2, C3: 10uF; CP_Elec_5x5.7
C4, C5, C6: 10nF; C_0805_2012Metric
C7, C10: 100nF; C_0805_2012Metric
C8: 3.9nF; C_0805_2012Metric
C9, C11: 1.5nF; C_0805_2012Metric
J1: IO; PinHeader_1x06_P2.54mm_Vertical
J2: PWM_VCO_In; THONKICONN_hole
J3: Synch; PinHeader_1x02_P2.54mm_Vertical
J5: AUX_IN; PinHeader_1x01_P2.54mm_Vertical
J6: AUX_OUT; PinHeader_1x01_P2.54mm_Vertical
J7: Power_In; PinHeader_1x03_P2.54mm_Vertical
J8: Power_In; PinHeader_1x04_P2.54mm_Vertical
J9: PWM_IN; PinHeader_1x01_P2.54mm_Vertical
J10: CV_IN; PinHeader_1x01_P2.54mm_Vertical
J11: CV_OUT; PinHeader_1x01_P2.54mm_Vertical
JP1: Freq_Jumper; PinHeader_1x02_P2.54mm_Vertical
JP2: PWM_Jumper; PinHeader_1x03_P2.54mm_Vertical
JP3: Tri_mix; PinHeader_1x02_P2.54mm_Vertical
JP4: Tri_jmp; PinHeader_1x02_P2.54mm_Vertical
JP5: Pulse_mix; PinHeader_1x02_P2.54mm_Vertical
JP6: Pulse_jmp; PinHeader_1x02_P2.54mm_Vertical
JP7: Saw_mix; PinHeader_1x02_P2.54mm_Vertical
JP8: Saw_jmp; PinHeader_1x02_P2.54mm_Vertical
JP9: Aux_mix; PinHeader_1x02_P2.54mm_Vertical
R1, R7: 267; R_0805_2012Metric
R2: 5k; Potentiometer_Piher_PT-6-V_Vertical
R3: 22.1k; R_0805_2012Metric
R4, R8: 49.9k; R_0805_2012Metric
R5: 4k3; R_0805_2012Metric
R6: 499k; R_0805_2012Metric
R9: 10k; R_0805_2012Metric
R10: 47k; R_0805_2012Metric
R11: 13k; R_0805_2012Metric
R12, R24: 100k; R_0805_2012Metric
R13: 2.2k; R_0805_2012Metric
R14, R17, R20: 120k; R_0805_2012Metric
R15, R16, R19: 30k; R_0805_2012Metric
R18: 36k; R_0805_2012Metric
R21: 18k; R_0805_2012Metric
R22: 75k; R_0805_2012Metric
R23: 51k; R_0805_2012Metric
R25: 160; R_0805_2012Metric
RV1: 5k; Alpha_9mm_Potentiometer_Aligned
RV2: 10k; Alpha_9mm_Potentiometer_Aligned
U1: AMS1117-5.0; SOT-223-3_TabPin2
U2: MCP1501-25xSN; SOIC-8_3.9x4.9mm_P1.27mm
U3: SSI2131; SOIC-16_3.9x9.9mm_P1.27mm
U4: LM4040DBZ-5; SOT-23
U5: MCP6002-xSN; MSOP-8_3x3mm_P0.65mm
U6: TL072; SO-8_3.9x4.9mm_P1.27mm
U7: 4066; TSSOP-14_4.4x5mm_P0.65mm
U8: LM4040DBZ-2.5; SOT-23

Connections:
+2V5: C1.2, J8.2, R3.2, R6.2, R25.2, RV1.1, U2.7 (OUT), U2.8 (FB), U3.14 (VREF), U5.8 (V+), U8.1 (K)
+5V: C3.1, J8.3, JP3.2, JP5.2, JP7.2, JP9.2, R25.1, U1.2 (VO), U2.1 (VDD), U2.3 (~SHDN), U3.16 (VDD), U7.14 (VDD)
+12V: C2.1, J7.1, RV2.1, U1.3 (VI), U6.8 (V+)
-5V: C10.1, J8.4, R10.2, R13.2, R20.2, R22.2, U4.2 (A)
-12V: C7.1, J7.3, R13.1, RV2.3, U3.7 (VSS), U6.4 (V-)
/EXPO_FREQ1: J1.4, R4.1
/EXPO_FREQ2: J1.5, R8.1
/HARD_SYNCH: C6.2, J3.1
/LIN_FREQ: JP1.1, U3.12 (LIN_FREQ)
/MIX_1: R17.1, R21.2, U6.1
/MIX_OUT: J1.6, R18.1, U6.7
/PULSE_MIX: R16.2, U7.10
/PULSE_OUT: J1.2, JP6.1, U3.2 (PULSE_OUT)
/PWM_Ctrl: JP2.2 (C), U3.3 (PWM_CTRL)
/PWM_pot: JP2.1 (A), RV1.2
/PWM_scaled_input: C9.2, JP2.3 (B), R11.1, U5.1
/SAW_MIX: R19.2, U7.2
/SAW_OUT: J1.1, JP8.1, U3.1 (SAW_OUT)
/SOFT_SYNCH: C5.2, J3.2
/TRI_MIX: R15.2, U7.9
/TRI_OUT: J1.3, JP4.1, U3.4 (TRI_OUT)
GND: C1.1, C2.2, C3.2, C4.2, C7.2, C8.1, C10.2, J2.1, J2.2, J7.2, J8.1, R5.1, R9.1, RV1.3, U1.1 (GND), U2.2 (GND), U2.4 (GND), U2.5 (GND), U2.6 (GND), U3.9 (GND), U4.1 (K), U5.3 (+), U5.4 (V-), U5.5 (+), U6.3 (+), U6.5 (+), U7.7 (VSS), U8.2 (A)
unnamed: C4.1, R1.2
unnamed: C5.1, U3.11 (SOFT_SYNC)
unnamed: C6.1, R9.2, U3.10 (HARD_SYNCH)
unnamed: C8.2, U3.8 (TCAP)
unnamed: C9.1, R10.1, R11.2, R12.1, R14.1, U5.2 (-)
unnamed: C11.1, R22.1, R23.2, R24.1, U5.6 (-)
unnamed: C11.2, J11.1, R23.1, U5.7
unnamed: J2.3, J9.1, R12.2
unnamed: J5.1, U7.4
unnamed: J6.1, U7.3
unnamed: J10.1, R24.2
unnamed: JP1.2, R6.1
unnamed: JP3.1, U7.6
unnamed: JP4.2, U7.8
unnamed: JP5.1, U7.12
unnamed: JP6.2, U7.11
unnamed: JP7.1, U7.13
unnamed: JP8.2, U7.1
unnamed: JP9.1, U7.5
unnamed: R1.1, U3.15 (BW_COMP)
unnamed: R2.1, U3.13 (EXPO_SCALE)
unnamed: R2.2, R3.1
unnamed: R4.2, R7.1, R8.2, U3.6 (EXPO_FREQ)
unnamed: R5.2, R7.2, U3.5 (HF_TRACK)
unnamed: R14.2, RV2.2
unnamed: R15.1, R16.1, R17.2, R19.1, R20.1, U6.2 (-)
unnamed: R18.2, R21.1, U6.6 (-)

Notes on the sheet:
VCO input assume input -10V to +10V: (-13/100) * +10 + (-13/47) * -5 = 0.08V (-13/100) * -10 + (-13/47) * -5 = 2.68V Pot input -12V to +12V: (-13/120) * +12 + (-13/47) * -5 = 0.08V (-13/120) * -12 + (-13/47) * -5 = 2.68V
First stage inverts and amplifies to -5V to 5V (-120/30) * 0 + (-120/120) * -5 = 5V (-120/30) * 2.5 + (-120/120) * -5 = -5V
3.9nF: Use C0G for low temp drift
2nd stage inverts and amplifies x2 (-36/18) * -5 = +10V (-36/18) * +5 = -10V
Inverting mixer calculation: -Vx * (Rfb / Rx)

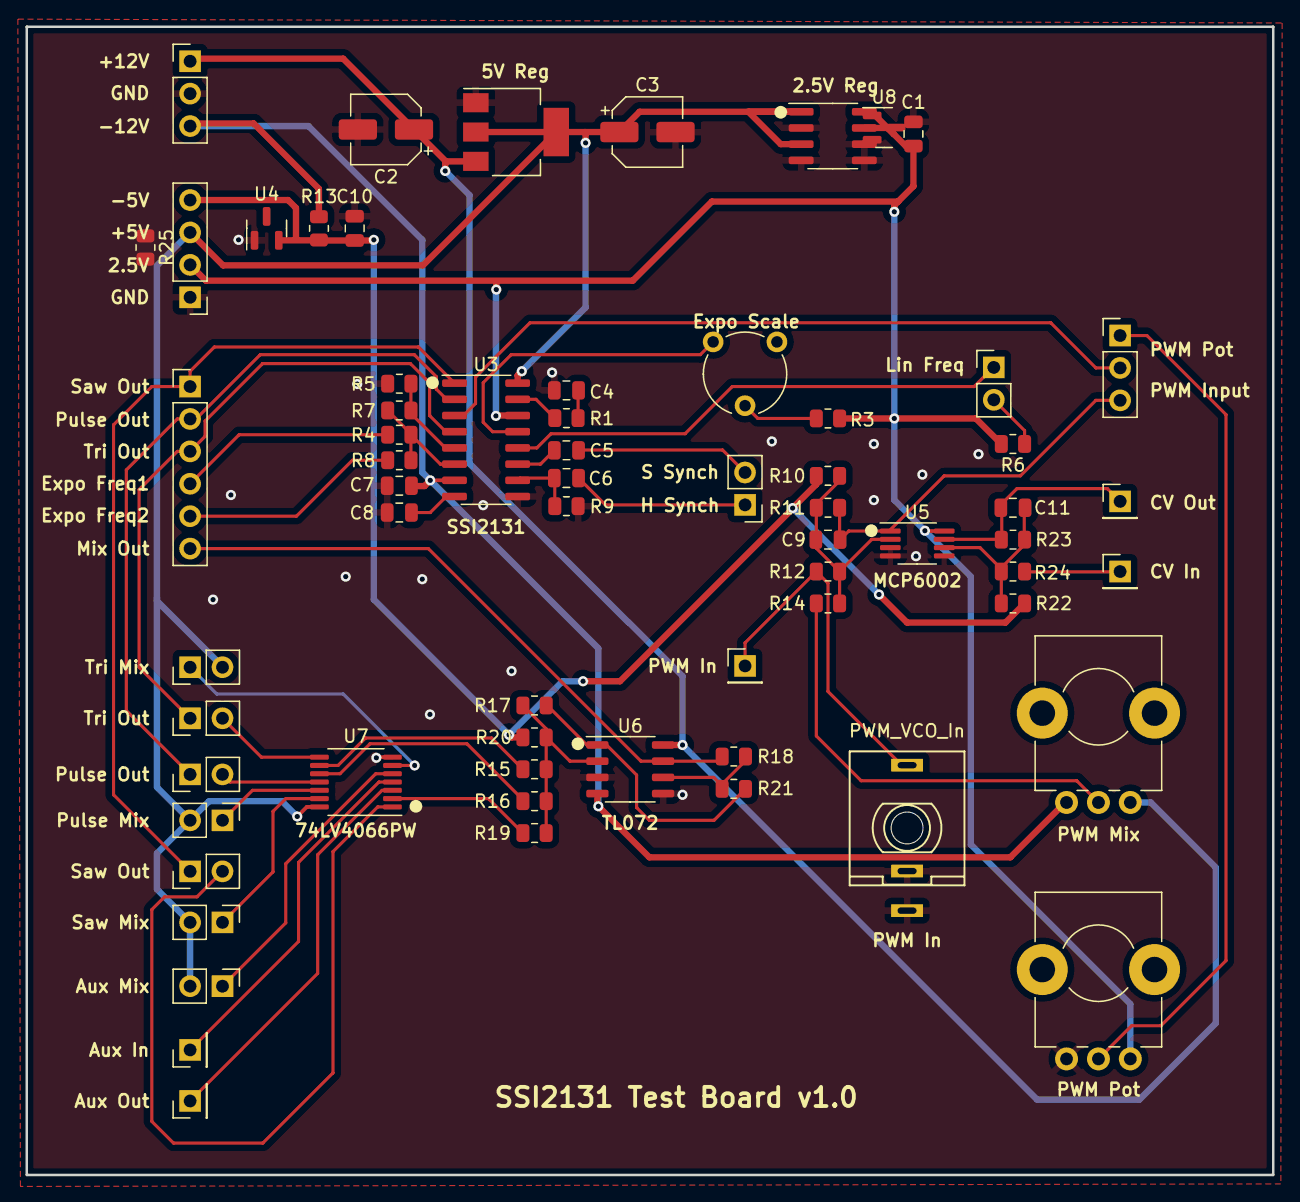
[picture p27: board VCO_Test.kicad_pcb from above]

Board: 2 copper layers, 97.7 x 90.0 mm, 65 parts (0 on the bottom side), 49 nets.

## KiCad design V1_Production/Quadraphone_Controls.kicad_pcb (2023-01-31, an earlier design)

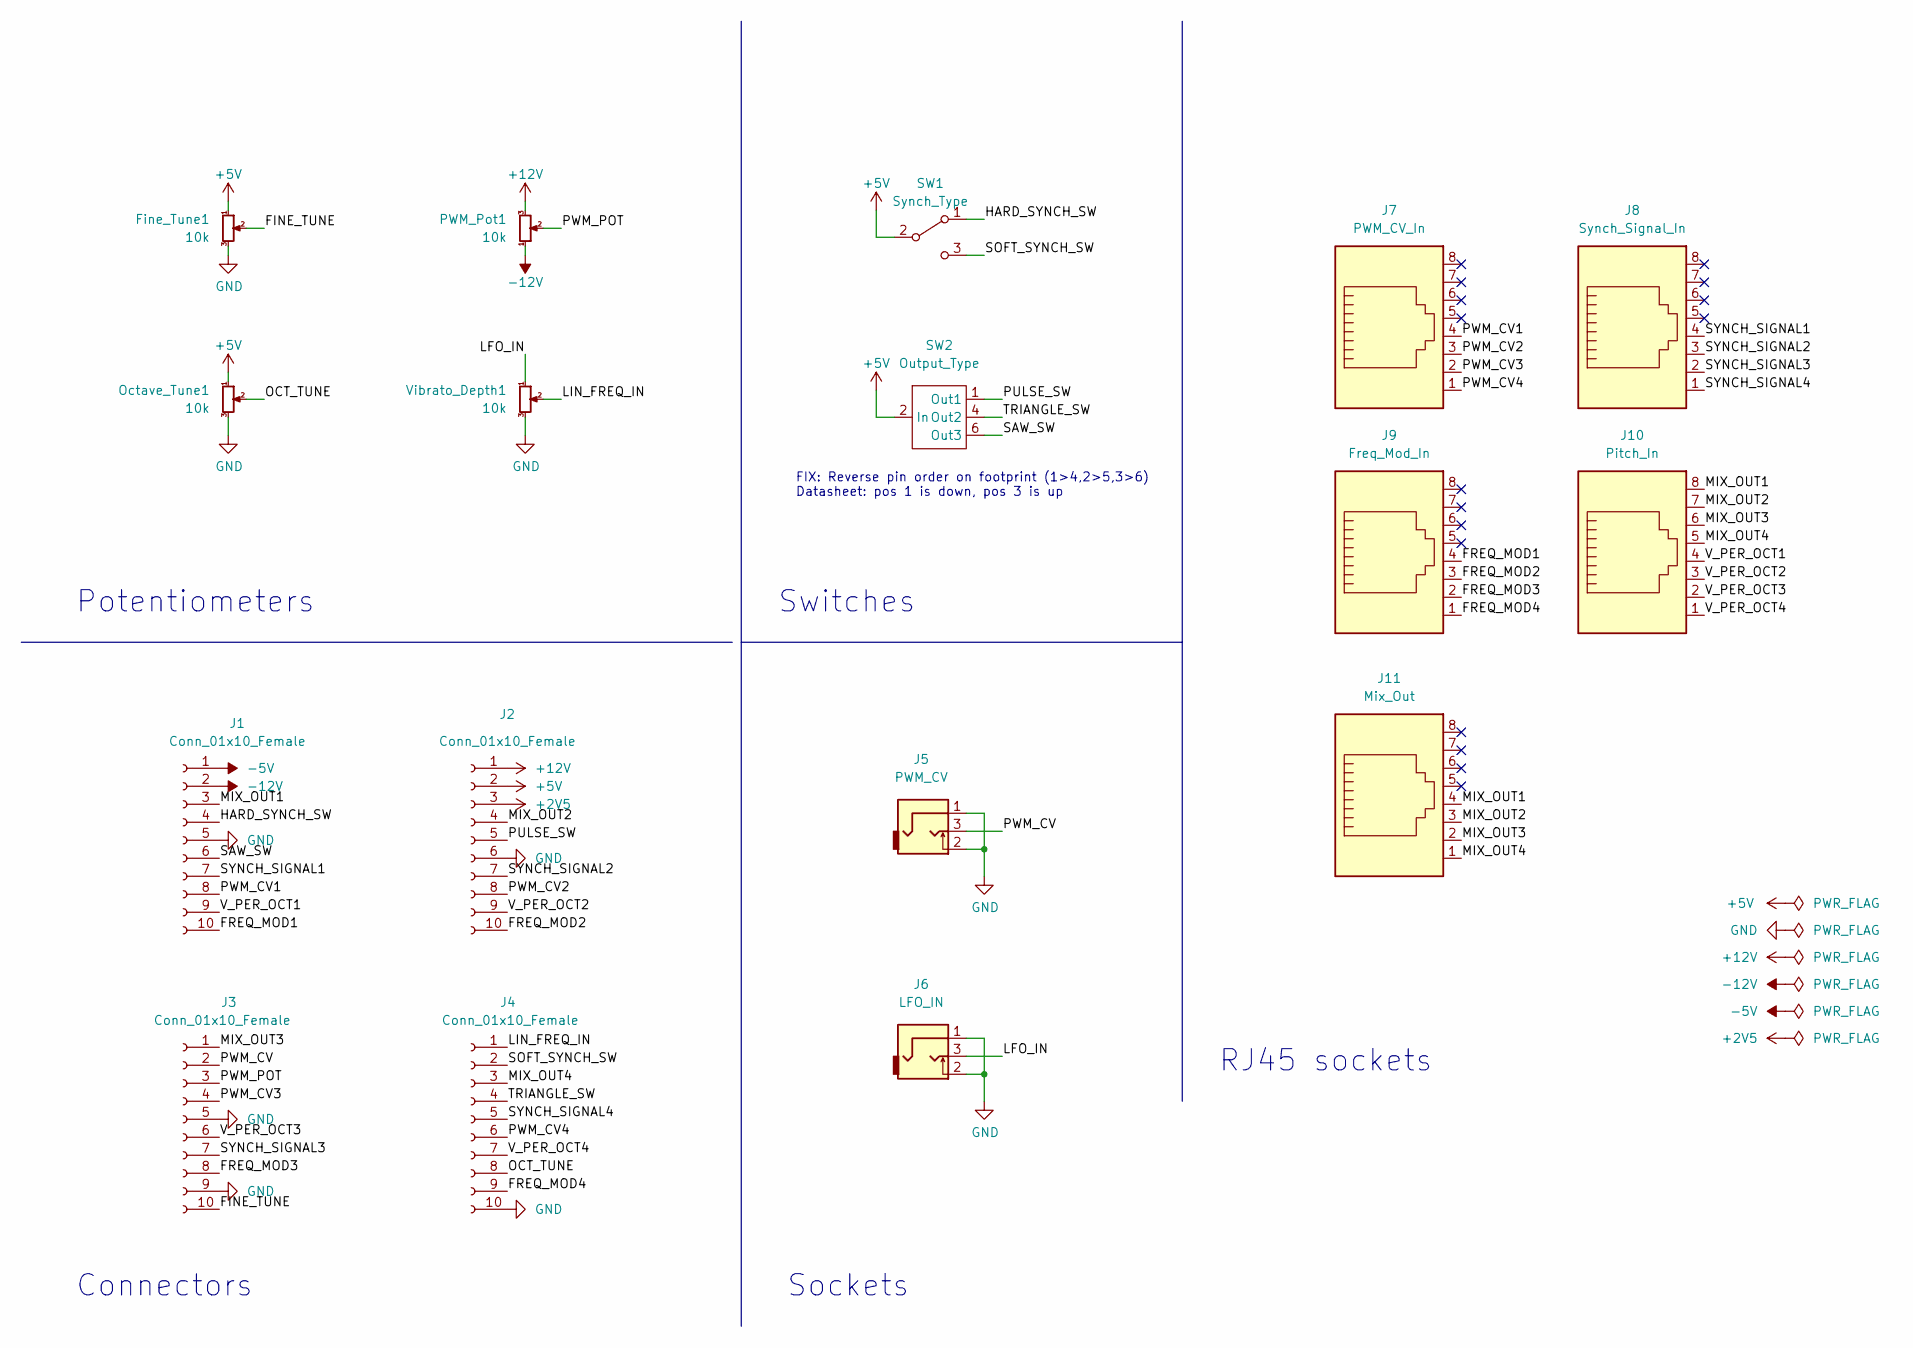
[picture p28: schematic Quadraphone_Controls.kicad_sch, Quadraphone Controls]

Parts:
Fine_Tune1: 10k; Alpha_9mm_Potentiometer_Aligned
J1, J2, J3, J4: Conn_01x10_Female; PinSocket_1x10_P2.54mm_Vertical
J5: PWM_CV; THONKICONN_hole
J6: LFO_IN; THONKICONN_hole
J7: PWM_CV_In; RJ45_Molex_42878-8506
J8: Synch_Signal_In; RJ45_Molex_42878-8506
J9: Freq_Mod_In; RJ45_Molex_42878-8506
J10: Pitch_In; RJ45_Molex_42878-8506
J11: Mix_Out; RJ45_Molex_42878-8506
Octave_Tune1: 10k; Alpha_9mm_Potentiometer_Aligned
PWM_Pot1: 10k; Alpha_9mm_Potentiometer_Aligned
SW1: Synch_Type; SPDTSubMiniature
SW2: Output_Type; SW_100DP3T1B1M2QEH
Vibrato_Depth1: 10k; Alpha_9mm_Potentiometer_Aligned

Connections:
+2V5: J2.3
+5V: Fine_Tune1.1, J2.2, Octave_Tune1.1, SW1.2 (B), SW2.2 (In)
+12V: J2.1, PWM_Pot1.3
-5V: J1.1
-12V: J1.2, PWM_Pot1.1
/FINE_TUNE: Fine_Tune1.2, J3.10
/FREQ_MOD1: J1.10, J9.4
/FREQ_MOD2: J2.10, J9.3
/FREQ_MOD3: J3.8, J9.2
/FREQ_MOD4: J4.9, J9.1
/HARD_SYNCH_SW: J1.4, SW1.1 (A)
/LFO_IN: J6.3, Vibrato_Depth1.1
/LIN_FREQ_IN: J4.1, Vibrato_Depth1.2
/MIX_OUT1: J1.3, J10.8, J11.4
/MIX_OUT2: J2.4, J10.7, J11.3
/MIX_OUT3: J3.1, J10.6, J11.2
/MIX_OUT4: J4.3, J10.5, J11.1
/OCT_TUNE: J4.8, Octave_Tune1.2
/PULSE_SW: J2.5, SW2.1 (Out1)
/PWM_CV: J3.2, J5.3
/PWM_CV1: J1.8, J7.4
/PWM_CV2: J2.8, J7.3
/PWM_CV3: J3.4, J7.2
/PWM_CV4: J4.6, J7.1
/PWM_POT: J3.3, PWM_Pot1.2
/SAW_SW: J1.6, SW2.6 (Out3)
/SOFT_SYNCH_SW: J4.2, SW1.3 (C)
/SYNCH_SIGNAL1: J1.7, J8.4
/SYNCH_SIGNAL2: J2.7, J8.3
/SYNCH_SIGNAL3: J3.7, J8.2
/SYNCH_SIGNAL4: J4.5, J8.1
/TRIANGLE_SW: J4.4, SW2.4 (Out2)
/V_PER_OCT1: J1.9, J10.4
/V_PER_OCT2: J2.9, J10.3
/V_PER_OCT3: J3.6, J10.2
/V_PER_OCT4: J4.7, J10.1
GND: Fine_Tune1.3, J1.5, J2.6, J3.5, J3.9, J4.10, J5.1, J5.2, J6.1, J6.2, Octave_Tune1.3, Vibrato_Depth1.3
unnamed: SW2.3 (Pin3), SW2.5 (Pin5)

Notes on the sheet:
Connectors
FIX: Reverse pin order on footprint (1>4,2>5,3>6) Datasheet: pos 1 is down, pos 3 is up
Potentiometers
RJ45 sockets
Switches
Sockets

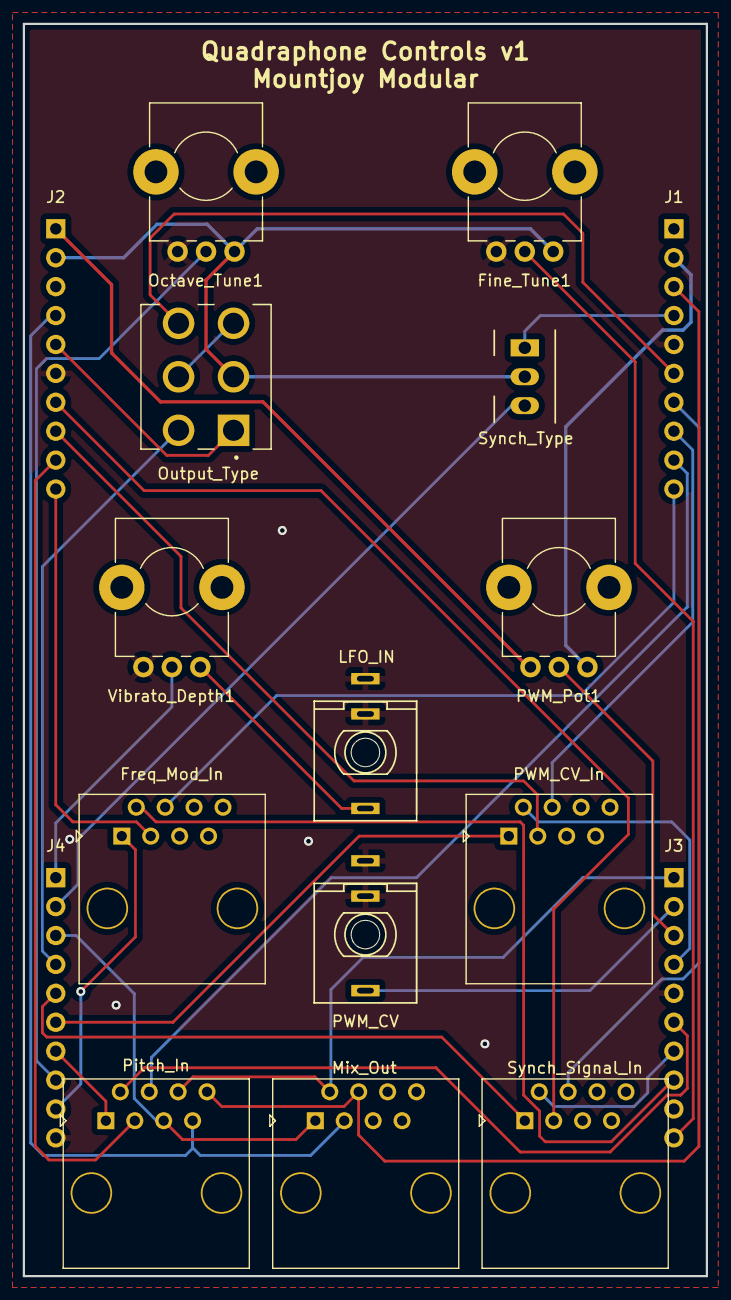
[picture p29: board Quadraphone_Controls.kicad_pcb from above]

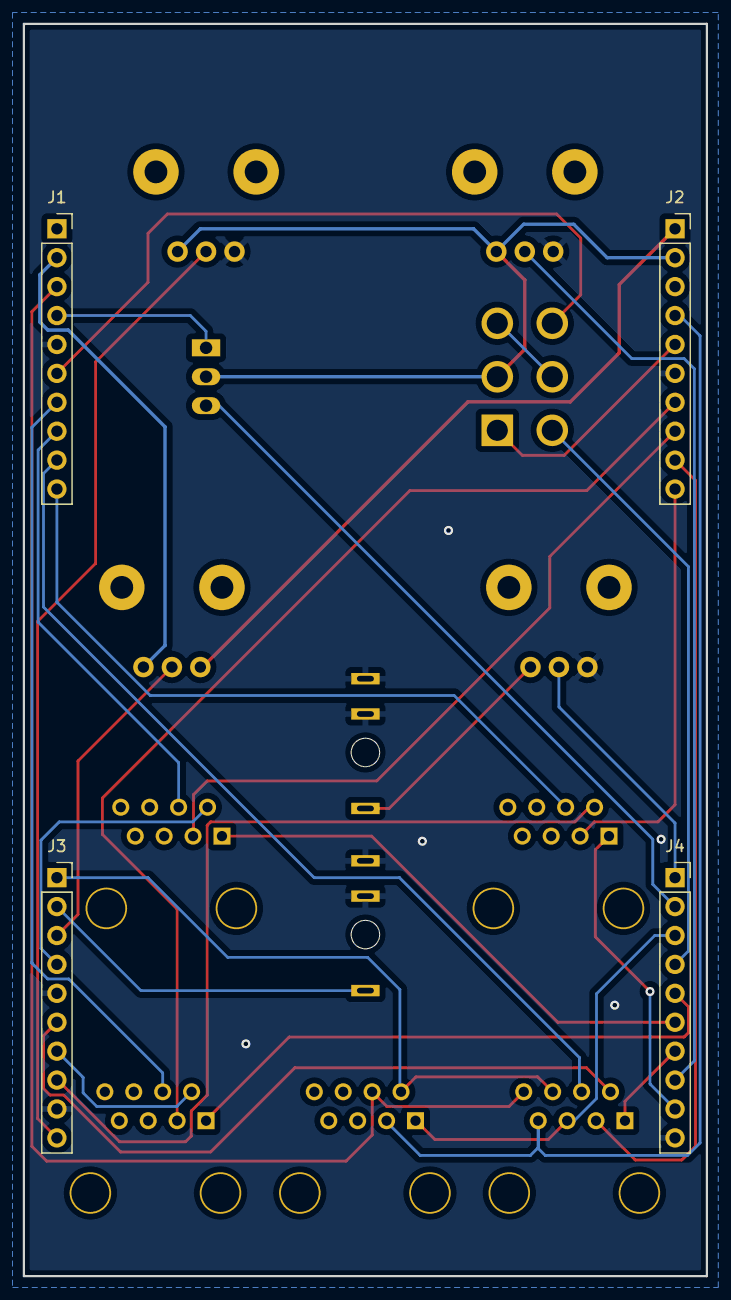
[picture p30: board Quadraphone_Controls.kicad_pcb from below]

Board: 2 copper layers, 60.0 x 110.0 mm, 17 parts (4 on the bottom side), 36 nets.

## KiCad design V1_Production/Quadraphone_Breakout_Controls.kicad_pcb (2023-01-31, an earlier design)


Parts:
J1: Mult_A; RJ45_Molex_42878-8506
J2: Mult_B; RJ45_Molex_42878-8506
J3: JackA1; THONKICONN_hole
J4: JackA2; THONKICONN_hole
J5: JackA3; THONKICONN_hole
J6: JackA4; THONKICONN_hole
J7: JackB1; THONKICONN_hole
J8: JackB2; THONKICONN_hole
J9: JackB3; THONKICONN_hole
J10: JackB4; THONKICONN_hole
J11, J12: Conn_02x04_Top_Bottom; PinHeader_2x04_P2.54mm_Vertical

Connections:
/A1: J1.1, J3.3, J11.1
/A2: J1.2, J4.3, J11.3
/A3: J1.3, J5.3, J11.5
/A4: J1.4, J6.3, J11.7
/A5: J1.5, J11.2
/A6: J1.6, J11.4
/A7: J1.7, J11.6
/A8: J1.8, J11.8
/B1: J2.1, J7.3, J12.1
/B2: J2.2, J8.3, J12.3
/B3: J2.3, J9.3, J12.5
/B4: J2.4, J10.3, J12.7
/B5: J2.5, J12.2
/B6: J2.6, J12.4
/B7: J2.7, J12.6
/B8: J2.8, J12.8
GND: J3.1, J4.1, J5.1, J6.1, J7.1, J8.1, J9.1, J10.1



Board: 2 copper layers, 18.8 x 110.0 mm, 12 parts (2 on the bottom side), 17 nets.

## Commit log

2022-12-24 Schematic Update
    [Quadraphone.kicad_sch]
2023-01-05 Voice schematic work; need to do linear FM
    [OSCVoice.kicad_sch, Quadraphone.kicad_sch]
2023-01-16 Split components and control pcbs
    [OSCVoice.kicad_sch, Quadraphone_Controls.kicad_pcb, Quadraphone_Controls.kicad_sch]
2023-01-17 Started PCB layout
    [OSCVoice.kicad_sch, Quadraphone.kicad_sch, Quadraphone_Controls.kicad_sch]
2023-01-18 Updated design to use buffered 2.5V reference
    [OSCVoice.kicad_sch, Quadraphone.kicad_pcb, Quadraphone.kicad_sch]
2023-01-18 Rough layout of one voice
    [OSCVoice.kicad_sch, Quadraphone.kicad_pcb, Quadraphone.kicad_sch]
2023-01-19 Duplicated layout of voices; power supply
    [OSCVoice.kicad_sch, Quadraphone.kicad_pcb, Quadraphone.kicad_sch]
2023-01-19 Routed majority of signal traces
    [Quadraphone.kicad_pcb, Quadraphone.kicad_sch]
2023-01-20 Clean up
    [Quadraphone.kicad_pcb]
2023-01-20 Converted to smaller 4 layer board
    [Quadraphone.kicad_pcb]
2023-01-20 Routing power rails
    [OSCVoice.kicad_sch, Quadraphone.kicad_pcb, Quadraphone.kicad_sch]
2023-01-20 Routed 2.5V Power Supply
2023-01-21 Started control board schematic
    [OSCVoice.kicad_sch, Quadraphone.kicad_pcb]
2023-01-22 Started laying out control board
    [Quadraphone.kicad_sch, Quadraphone_Controls.kicad_pcb, Quadraphone_Controls.kicad_sch]
2023-01-23 Started laying out Panel
    [Quadraphone.kicad_pcb, Quadraphone.kicad_sch, Quadraphone_Controls.kicad_pcb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]
2023-01-24 Rough Layout of Panel
    [Quadraphone_Controls.kicad_pcb, Quadraphone_Panel.kicad_pcb]
2023-01-25 First draft panel done
    [Quadraphone.kicad_pcb, Quadraphone_Controls.kicad_pcb, Quadraphone_Panel.kicad_pcb]
2023-01-26 Refinements to panel and controls
    [Quadraphone_Controls.kicad_pcb, Quadraphone_Controls.kicad_sch]
2023-01-27 Fixed ground connections on component board
    Added JLC PCB plug-in
    Schematic clean-up
    [BOM-Quadraphone.csv, OSCVoice.kicad_sch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]
2023-01-27 Added RJ45 breakout module
    [Quadraphone.kicad_pcb, Quadraphone.kicad_sch, Quadraphone_Breakout_Controls.kicad_pcb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]
2023-01-29 Prepared all gerbers
    [BOM-Quadraphone.csv, OSCVoice.kicad_sch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]
2023-01-31 Fixed issue with hole for voice switch size
    [Quadraphone.kicad_pcb, Quadraphone_Breakout_Controls.kicad_pcb, Quadraphone_Breakout_Panel.step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]
2023-02-20 Updates for v2 on control board
    [OSCVoice.kicad_sch, Quadraphone.kicad_pcb, Quadraphone.kicad_sch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]
2023-03-03 Clean up control board
    [Quadraphone_Controls-B_Cu.gbr, Quadraphone_Controls-B_Mask.gbr, Quadraphone_Controls-B_Paste.gbr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]
2023-03-22 Added readme
    [OSCVoice.kicad_sch, Quadraphone.kicad_sch, Quadraphone_Breakout_Controls.kicad_pcb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]
2023-03-29 Fixes to footprints on controls board
    [Quadraphone_Controls-B_Cu.gbr, Quadraphone_Controls-B_Mask.gbr, Quadraphone_Controls-B_Paste.gbr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]
2023-04-04 v2.0 Update with Synch pulse at start to fix oscillators not starting
    [OSCVoice.kicad_sch, Quadraphone.kicad_pcb, Quadraphone.kicad_sch]
2023-04-05 Completed layout of synch pulse modification
    [Quadraphone.kicad_pcb]
2023-04-16 Updated production files for version 2 (Start up pulse)
    [BOM-Quadraphone.csv, OSCVoice.kicad_sch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]
2023-04-28 Added alternative control pcb layout with 3 way switch for octave
    [OSCVoice.kicad_sch, Quadraphone.kicad_pcb, Quadraphone.kicad_sch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]
2023-04-30 Create gerbers for control board changes;
    Notes for potential v3 component revision
    [Quadraphone.kicad_sch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]
2023-05-28 Started Rev 3 with buffered octave control
    [OSCVoice.kicad_sch, Quadraphone.kicad_pcb, Quadraphone.kicad_sch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]
2023-08-12 Updates to v3; changed output mix feedback resistors to lower output level
    [BOM-Quadraphone.csv, OSCVoice.kicad_sch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]
2023-08-14 Updates for v3 production
    [BOM-Quadraphone_Components.csv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]
2023-08-15 Updates to controls Synch input protection
    [OSCVoice.kicad_sch, Quadraphone_Components.kicad_sch, Quadraphone_Controls_v3.kicad_pcb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]
2023-08-17 Updated resistor values in VCO tuning circuits
    [BOM-Quadraphone.csv, BOM-Quadraphone_Components.csv, OSCVoice.kicad_sch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]
2023-08-21 Gerbers Prepared and Ordered
    [BOM-Quadraphone_Components.csv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]
